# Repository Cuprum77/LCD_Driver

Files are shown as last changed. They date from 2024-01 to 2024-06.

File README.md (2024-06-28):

# LCD Driver Project

This repository contains my attempt at creating a "universal" driver board that fits most of the new 40 pin LCDs from China. These new LCDs all utilize a 40 pin flat flex cable, and utilize the ST7701 driver IC. 
This means that they are rather simple RGB devices, not too unlike the old VGA standard. 
The main goal however, is to have a board that does not require any system drivers, and utilize the standard connectors that are available on most SBCs, such as the Raspberry Pi, as well as most laptops and desktops.

## Table of contents
- [Supported LCDs](#supported-lcds)
- [Project layout](#project-layout)
- [License](#license)

## Supported LCDs

This table lists the LCDs that I have bought and tested with the driver board.

| Format | Size  | Resolution | Driver IC | Touch | Link | Additional notes |
| --- | ----- | --- | --- | ----- | --- | --- |
| Bar | 3.99" | 400x960 | ST7701 | Yes | [AliExpress](https://www.aliexpress.com/item/1005005622337201.html) | |
| Square | 3.95" | 480x480 | ST7701 | Yes | [AliExpress](https://www.aliexpress.com/item/1005005230886441.html) | NOT FULLY TESTED YET |

Alternatively, any other board that uses the ST7701 driver IC and with the following [pinout](./resources/PINOUT.md) should work with the driver board. However, you must generate a new ROM file for the FPGA.

## Project layout
- [UVVM_Light](https://github.com/UVVM/UVVM_Light) - The UVVM framework
- [bitfiles](bitfiles/) - FPGA bitfiles
- [edid](edid/) - EDID files for the LCDs
- [hardware](hardware/) - The KiCad project files for the driver boards
- [resources](resources/) - Resources for the project, such as datasheets
- [rom](rom/) - The ROM files for the FPGA projects
- [sim](sim/) - The UVVM testbenches for the driver boards
- [software](software/) - The software for the driver boards
- [vivado-library](https://github.com/Digilent/vivado-library/) - The Vivado library files for the driver boards

## License
This project is licensed under CERN Open Hardware License Version 2 - Strong Reciprocity (CERN-OHL-S-2.0). See [LICENSE](LICENSE) for more details.
Note that some files in this repository may be licensed under different licenses. Please check the respective files for more information.

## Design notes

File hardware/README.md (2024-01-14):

# Hardware

This repo contains the KiCAD files for the current hardware prototypes of the LCD driver board.

## Current version

The latest board manufactured is the [Breakout_1](Breakout_1/) board. This PCB is a breakout board for the LCD display, which allows for easy testing and verification of the display. It also contains a 40 pin header for the LCD display itself and a PMOD interface for hooking up with a FPGA board.

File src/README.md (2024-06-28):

# FPGA Source Files

This directory contains the FPGA source files for each specific FPGA board.
Each variant has its own subdirectory and the files may differ between the variants.

## ISE specifics

The ISE source files are located in the `ise` subdirectory, these contain the following file from [tmatsuya](https://github.com/tmatsuya)'s [repository](https://github.com/tmatsuya/i2c_edid): `i2c_edid.v`. Their respective license must be followed.

The folder `ise` also requires the user to request the `xapp460.zip` file from Xilinx, as it contains the DVI decoder used in this project. This is not possible to include in this repository as source code due to licensing restrictions.
It can be requested from their [application note](https://docs.amd.com/v/u/en-US/xapp460) near the end of the document.

The following files are required from the `XAPP460` note:
- `chnlbond.v`
- `dcminit.v`
- `decode.v`
- `DRAM16XN.v`
- `dvi_decoder.v`
- `phsaligner.v`
- `tmds_1c_1to10.v`

You also need to generate the appropriate edid.hex file for your display. This can be done with the python script [`edid_to_ise.py`](../edid/edid_to_ise.py) in the `edid` folder.

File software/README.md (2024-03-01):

# Firmware

The firmware, written in C/C++, is designed to operate on the RP2040 microcontroller. Its primary function is to read data from the capacitive touch sensor and transmit it to the host computer over USB.

The challenge lies in dealing with the capacitive touch sensor, an unidentified device. Fortunately, the touch controller on the display's flat flex cable retains its markings, making identification possible. The touch controller in use is the GT911 from Goodix, utilizing the I2C protocol.

Based on the similar AVR project by [azukovskij89](https://github.com/azukovskij89/AVR-MultiTouch).

## Chip Identification
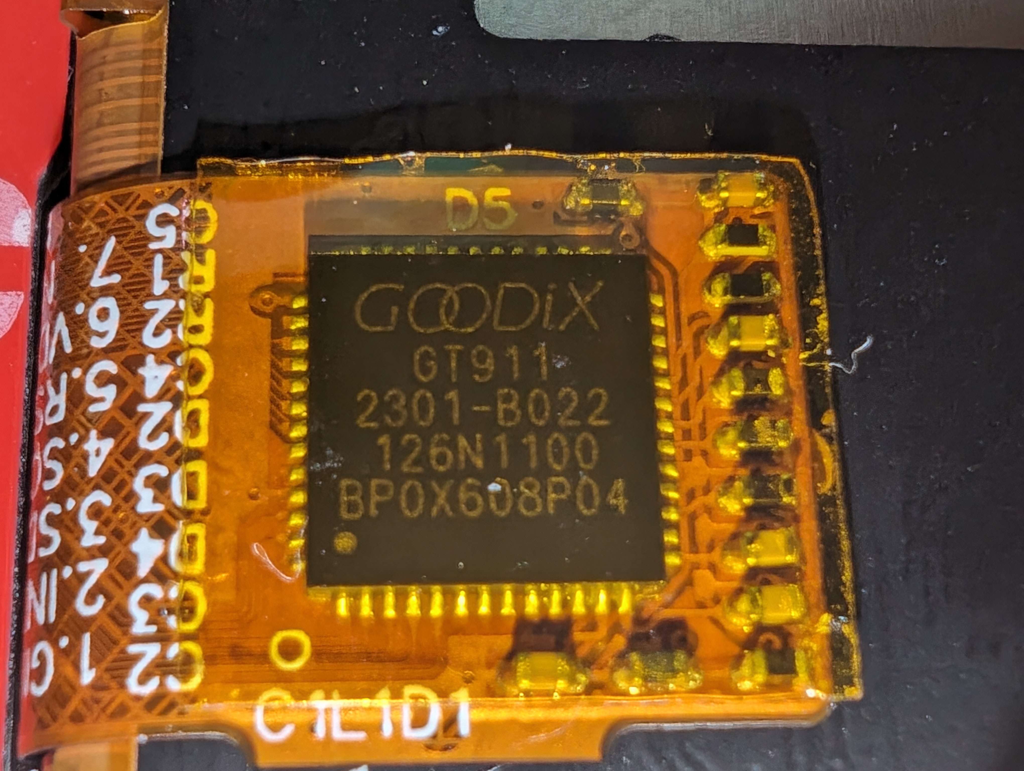
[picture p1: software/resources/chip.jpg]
Chip

Above is a close-up image of the GT911 chip on the flat flex cable of this specific display.

## Resources
- [Datasheet](../resources/GT911_v.09.pdf): Provides a brief overview of the chip's features and specifications.
- [Programming Guide](../resources/GT911%20Programming%20Guide_v0.1.pdf): Contains the register map and programming instructions.

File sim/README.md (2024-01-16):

# Simulation

This folder contains the files that were used for simulation of this project. Each folder contains a readme file that describes the simulation and its goals in more detail.

## Structure

The subfolders each contains a simulation for a specific part of the project, with the exception of the `UVVM` folder which contains the compiled UVVM library, which you need to compile in order to run the simulations.

The subfolders are structured as follows:
- [resetter](resetter/) - Simulation of the resetter
- [rgb](rgb/) - Simulation of the RGB controller for interfacing with the screen
- [spi](spi/) - Simulation of the SPI interface
- [sequencer](sequencer/) - Simulation of the sequencer (with the SPI interface)
- [top](top/) - Simulation of the top level module (with the sequencer and the RGB controller)

## Compiling UVVM

To compile UVVM for ModelSim, you need to open ModelSim and run the following snippet in the transcript window:

```tcl
do ../../UVVM_Light/script/compile.do ../../UVVM_Light ../UVVM
```

This should compile the UVVM library and place it in the `UVVM` folder.

## Running the simulations

Note, all UVVM based testbenches need to be configured to use VHDL-2008 or the simulation will throw errors!

Simply open up any of the project files in ModelSim and run the simulation.
The UVVM framework should be automatically loaded from the `UVVM` folder assuming you have compiled it correctly.

## UVVM Documentation

The documentation can be found [here](https://uvvm.github.io/), with the specific library used in this project located [here](https://uvvm.github.io/utility_library.html).

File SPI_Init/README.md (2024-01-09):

# FPGA SPI Hardware

This repo contains the hardware implementation of the SPI protocol for the FPGA. The SPI protocol is used to communicate with the LCD display.

## Table of contents
  - [SPI](#spi)
    - [Port map](#port-map)
    - [Bit Width](#bit-width)
  - [Sequencer](#sequencer)
    - [Port map](#port-map-1)
    - [Instruction Set](#instruction-set)
        - [cmd](#cmd)
        - [cmd_data](#cmd_data)
        - [size](#size)
        - [data](#data)
        - [data_cont](#data_cont)
        - [wait](#wait)
        - [Example](#example)
    - [ROM](#rom)
    - [ROM Generator](#rom-generator)
    - [Error](#error)

## SPI
The SPI is a state machine that makes sure the bits are sent out in the correct order and at the correct time. The implemented can be found in the file [spi.vhd](/spi.vhd).

Unlike other SPI implementations, this is master only. Meaning that it can only transmit data and not receive it. This is because the LCD display doesn't need to send any data back to the FPGA.

### Port map
| Port name | Direction | Size (bits) | Behavior | Description |
|---|---|---|---|---|
| clk | in | 1 | Active HIGH | Global clock |
| reset | in | 1 | Active HIGH | Global reset |
| spi_sda | out | 1 | | SPI data |
| spi_scl | out | 1 | | SPI clock |
| spi_cs | out | 1 | | SPI chip select |
| spi_dc | out | 1 | | SPI data command |
| send | in | 1 | Active HIGH | Start the transmission |
| set_dc | in | 1 | Active HIGH | Enables/Disables the SPI data command |
| done | out | 1 | LOW during transmission | Idle signal |
| data | in | 32 | MSB | Data to be sent over the bus |
| bit_width | in | 3 | | Number of bits to send over the bus |

### Bit Width
The `bit_width` variable is special, as it allows us to vary the number of bits being sent out over the SPI bus. This is very useful for some displays where the entire pixel should be sent at once, like the ST7789V displays. Thus it needs to be set to the correct setting for the number of bytes being sent:

| `bit_width` | Number of bits |
|---|---|
| 0 | 8 bits |
| 1 | 16 bits |
| 2 | 18 bits |
| 3 | 24 bits |
| 4 | 32 bits |

The state machine will start at the `bit_width` setting, so if you select 8 bits, it will start at index 7 of your data and work its way down to 0.

Warning; you still need to provide the entire 32 bits to the component even if you don't need every bit. Simply pad out the remaining bits with whatever you want if you use less than 32 bits.

## Sequencer
The sequencer is a state machine that takes in instructions from a generated ROM file and sends them to the SPI component. The implemented can be found in the file [sequencer.vhd](/sequencer.vhd).

This will execute every instruction in the ROM file, and will stop if it encounters an error. This is to prevent the sequencer from sending out garbage data to the LCD display.

When the sequencer is done, it will enter an idle state and stay there until it is reset.

### Port map

| Port name | Direction | Size (bits) | Behavior | Description |
|---|---|---|---|---|
| clk | in | 1 | Active HIGH | Global clock |
| reset | in | 1 | Active HIGH | Global reset |
| spi_sda | out | 1 | | SPI data |
| spi_scl | out | 1 | | SPI clock |
| spi_cs | out | 1 | | SPI chip select |
| spi_dc | out | 1 | | SPI data command |
| done | out | 1 | HIGH when done | Turns on when the module is done |
| sequence_error | out  | 1 | HIGH on error | Error signal |

### Instruction Set
The sequencer is used to send commands to the LCD display. To make it as versitile as possible, it uses a very simple instruction set.

An important thing to note is that the ROM is 32 bits wide, and loads two such words per cycle. This means that the first word is the instruction, and the second word is the payload.

| Instruction | Hex Code | Description |
|---|---|---|
| cmd | 0x10 | Send a command to the LCD display |
| size | 0x20 | Set the size of the data |
| data | 0x21 | Send data to the LCD display |
| wait | 0x30 | Delay in milliseconds |

#### cmd
The `cmd` instruction is used to send a command to the LCD display.
This behaves similarly to the `data` instruction, but it will also set the size to 8 bits automatically. Saves you a few instructions.

#### size
The `size` instruction is used to set the number of bits to send over the SPI bus. This is useful for commands that require a different number of bits to be sent.

The number written here should match one the possible values for the `bit_width` variable as described in [Bit Width](#bit-width).
Failure to match the `bit_width` variable will result in the module throwing an error.

#### data
The `data` instruction is used to send data to the LCD display.

Should always be preceded by a `size` instruction. If not, it will default to whatever was set before. Usually 8 bits if previous instruction was a `cmd` instruction.

#### wait
The `wait` instruction is used to delay the sequencer for a given number of milliseconds.

The sequencer will convert the number of milliseconds to the number of clock cycles required to wait.

The maximum wait time is 1 000 ms.

#### Example
The following example shows how to configure the cursor's x position on a ST7789V display;
```
cmd 0x2a
size 32
data 0x00 0x00 0xef 0x00
```
This psuedo code can be fed into the ROM generator to create a ROM.vhd file, found at [ROM Generator](#rom-generator).

### ROM
The ROM is a generated file that contains the instructions for the sequencer. It is a VHDL file that contains a constant array thats 32 bits wide and as long as the number of instructions in the ROM minus the number of comments.

This should be generated using the [ROM Generator](#rom-generator).

### ROM Generator
The ROM generator is a python script that takes in a text file containing the instructions for the Sequencer and outputs a VHDL file containing the ROM needed for the Sequencer to synthesize.

The script can be found at [rom_generator.py](/rom_generator.py).

The script expects a text file containing the instructions for the sequencer. Each instruction should be on its own line, and the instruction and its payload should be separated by a space.

An example of a valid instruction file for an ST7789V display can be found [here](/Example/st7789v_instructions.txt).

### Error
If the sequence encounters an unexpected instruction, it will throw an error and stop the sequence. This is to prevent the sequencer from sending out garbage data to the LCD display.

To exit the error state, the system needs to be reset.

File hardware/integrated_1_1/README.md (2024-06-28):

# Integrated Solution Rev 1.1

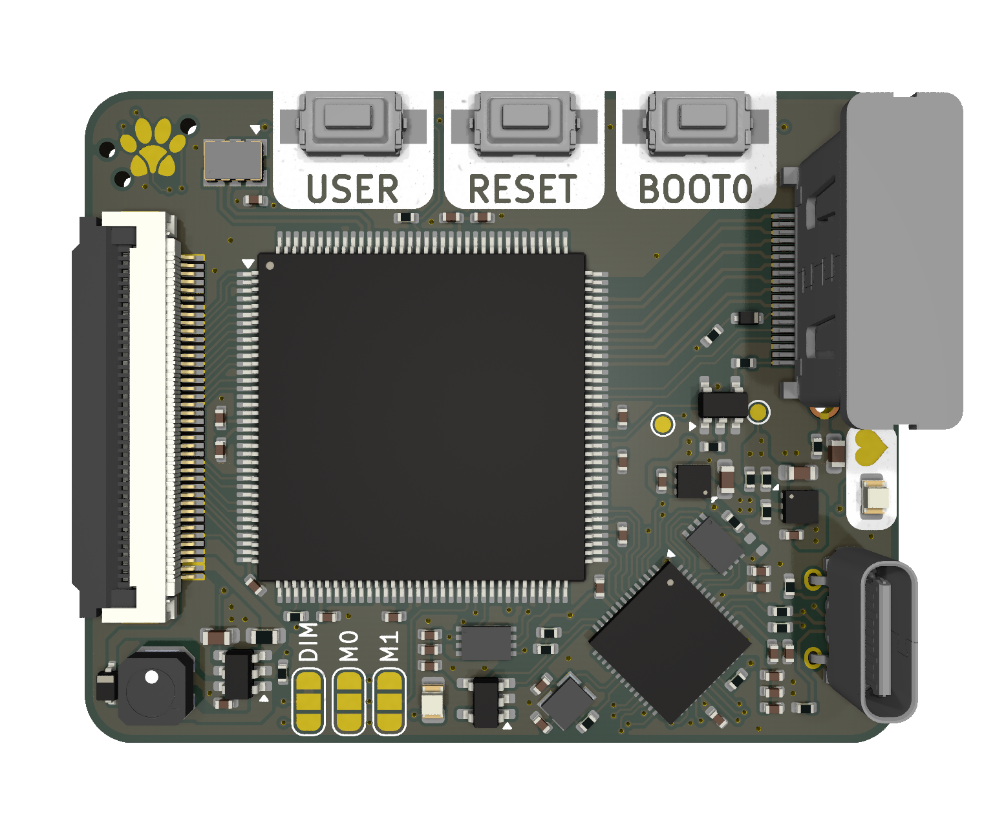
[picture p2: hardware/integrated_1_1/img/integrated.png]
Integrated


## Introduction

Even smaller than the previous revision, this design is a complete redesign of the previous, and implements fixes for the critical errors in the previous design. This design is still in the prototype phase and is not ready for production.

This is a PCB that integrates everything needed to drive the display. It is designed to sit on the back of the display without interfering with the display frame. It is specifically designed for the pinout of the newer non-standard displays that have come out of China in the recent years. Specifically those that support the RGB666 interface.

This design utilizes a Spartan 6 FPGA to drive the display. This was chosen over dedicated ASICs due to cost and adaptability. This should allow me to add features such as a splash screen or other custom features that are not possible with a dedicated ASIC.

## Features
- Spartan 6 FPGA [^1]
- DVI Input [^2]
- RP2040 microcontroller
- USB-C [^3] [^4]
- Backlight driver with dimming control
- LCD connector

[^1]: XC6SLX9-TQG144
[^2]: The DVI input is over a HDMI-like connector. This is due to licensing issues with the HDMI standard that I cannot afford to pay for. Any reference to HDMI in this project is purely for the sake of simplicity and is not meant to imply that this project is HDMI compatible.
[^3]: Does not support PD.
[^4]: Limited to USB 1.1 speeds. This is limited by the RP2040 which handles the USB interface.

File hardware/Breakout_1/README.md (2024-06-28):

# Breakout Board
Note, this is not a complete project. It lacks the necessary files to properly modify the design. This is purely out of the fact that this is a prototype and I am too lazy to properly document it.

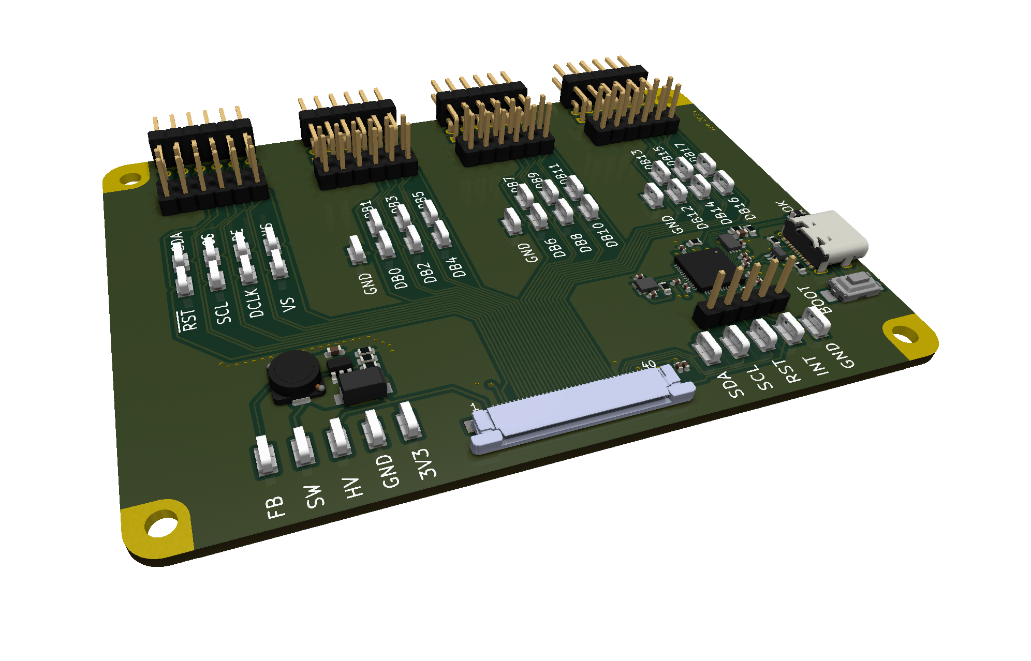
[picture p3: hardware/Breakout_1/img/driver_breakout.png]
Breakout design


This repo contains the KiCAD files for the first iteration of this project, the breakout board.

## Known Issues

These are the known issues with the current design:
- No pull-up resistors on the I2C lines
- No reset button
- No ability to power the board from the USB port (for the microcontroller)
- Difficult to add external power to the board
- More ground connections!
- Boost Converter is not capable of providing enough current for the display. Does not match the chips rated output.

## 3D Files

In the [3D](./3d/) folder you can find the 3D models for the board and a stand for the display to rest on.
The [stand](./3d/stand.stl) is a very crude design. It may not be very printable, but it works well enough for a prototype. 

This will not be developed further as there will not be a need for it in the final design.

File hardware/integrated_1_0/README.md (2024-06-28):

# Integrated Solution rev 1.0

## DO NOT REPRODUCE, CRITICAL ERRORS IN DESIGN

This design features a nasty error where the internal and IO power rails were accidentally swapped. Do not reproduce this design. A new revision is in the works.

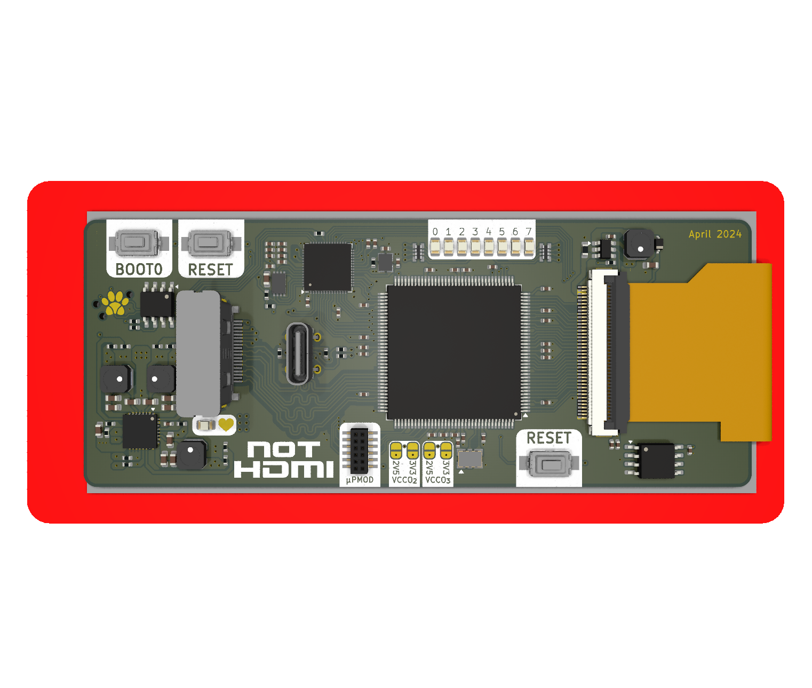
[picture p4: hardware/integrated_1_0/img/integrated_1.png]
Integrated


## Introduction

This is a PCB that integrates everything needed to drive the display. It is designed to sit on the back of the display without interfering with the display frame. It is specifically designed for the pinout of the newer non-standard displays that have come out of China in the recent years. Specifically those that support the RGB666 interface.

This design utilizes a Spartan 6 FPGA to drive the display. This was chosen over dedicated ASICs due to cost and adaptability. This should allow me to add features such as a splash screen or other custom features that are not possible with a dedicated ASIC.

## Features
- Spartan 6 FPGA [^1]
- DVI Input [^2]
- RP2040 microcontroller
- USB-C [^3] [^4]
- Backlight driver with dimming control
- LCD connector

## LCD Connector

The LCD connector itself is a ZIF 40 pin 0.5mm pitch connector.
The following pinout is in use, with some pins being possible to reconfigure in the FPGA:

TO BE ADDED

[^1]: XC6SLX9-TQG144
[^2]: The DVI input is over a HDMI-like connector. This is due to licensing issues with the HDMI standard that I cannot afford to pay for. Any reference to HDMI in this project is purely for the sake of simplicity and is not meant to imply that this project is HDMI compatible.
[^3]: Does not support PD.
[^4]: Limited to USB 1.1 speeds. This is limited by the RP2040 which handles the USB interface.

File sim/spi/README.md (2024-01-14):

# Simulation of the SPI

This is the files for the SPI simulation. The simulation is done using ModelSim and the [UVVM](https://github.com/UVVM/UVVM_Light) framework.

## Simulation

The goal of this simulation is to verify the functionality of the SPI interface and that it outputs the correct data when it should.

Note, the module is somewhat limited by design. It will not prevent the user from changing the input during transmission, and it will not ignore them either. This means that if the user changes the `data` input during transmission, the module will send the new data instead of the old. This is something to keep in mind when using the module, which is also why the `DONE` signal is important.

## Simulation Setup

There are a few things that I want to test with this module, and they are as follows:
- [Case 1](#case-1): Reset behaves as expected
- [Case 2](#case-2): `SEND` is ignored during reset and transmission
- [Case 3](#case-3): The `DONE` line is set correctly
- [Case 4](#case-4): Bit order can be changed

If these all pass, including a manual verification that the timings are correct, then the module should be ready for use.

### Case 1

The data lines should be set to their respective values after a reset:

| Line | Value |
| --- | ----- |
| SPI_SDA  | 0 |
| SPI_SCL  | 0 |
| SPI_CS | 1 |
| DONE | 1 |

Even if the `SEND` line is set to HIGH during reset, the module should not send any data.

### Case 2

The `SEND` line should be ignored during a reset state.
This means that if we want to transmit anything, but we reset it at the same time, it should still reset.

This is done by simply sending a reset and send pulse at the same time.

### Case 3

We need to verify that the `DONE` signal is kept HIGH when its not transmitting, and set LOW when it is.
This is critical for telling any higher level function that we are busy and shouldn't be bothered.

We will do this test with 8 bits, and the signal 0xAA.

### Case 4

Replicate [Case 3](#case-3), but do so with all the bit orders possible. Signal should be 0xAAAAAAAA to make it easy to spot visually.
We also care about the bits being sent in this scenario.

This test will conduct one transmission for each bit width setting.

## Results

The results can be viewed in the [log file](SPI_log.txt).
If there were any problems, they will show in the [alert file](_Alert.txt). This file will be empty if there were no problems.

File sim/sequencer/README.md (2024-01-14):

# Simulation of the Sequencer

This is the files for the Sequencer simulation. The simulation is done using ModelSim and the [UVVM](https://github.com/UVVM/UVVM_Light) framework.

## Simulation

The goal of this simulation is to verify the functionality of the sequencer and that it outputs the correct data when it should.
However, unlike the SPI simulation, this simulation will not provide any actual data to test. That is the job of the ROM.

This means you need to generate your own ROM file to test the sequencer with. This is done by ruinning the [ROM generator](../../SPI_Init/rom_generator.py) script.
The assembly file used for this simulation can be found [here](data.txt).

We will also not test any of the SPI functionality, as that module is assumed to be working correctly following a successful simulation.

## Simulation Setup

The sequencer is a lot simpler than the SPI module in terms of if it works or not. Either it outputs the SPI data correctly, or it doesn't.
This makes it significantly easier to test, as we can simply verify that the data is correct with a given input, such as the one provided in this folder.

Please note that the simulation will fail without the correct ROM file, as it is expecting the same data as the ROM file provides.

Note, there are only 8 bit instructions being used in this simulation.

## Results

The results can be viewed in the [log file](Sequencer_log.txt).
If there were any problems, they will show in the [alert file](_Alert.txt). This file will be empty if there were no problems.

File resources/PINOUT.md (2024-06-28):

# LCD Pinout

| Pin | Name | Description |
| --- | --- | --- |
| 1 | LEDA | Backlight Anode |
| 2 | LEDK | Backlight Cathode |
| 3 | LEDK | Backlight Cathode |
| 4 | GND | Ground |
| 5 | VCC | Power 3.3V |
| 6 | RST_n | Reset, active low |
| 7 | NC | Not connected |
| 8 | NC | Not connected |
| 9 | SDA | SPI Data |
| 10 | SCL | SPI Clock |
| 11 | CS | SPI Chip Select |
| 12 | DCLK | RGB Dot Clock |
| 13 | DE | RGB Data Enable |
| 14 | VSYNC | RGB Vertical Sync |
| 15 | HSYNC | RGB Horizontal Sync |
| 16 | DB0 | RGB Data Bit 0 (Blue) |
| 17 | DB1 | RGB Data Bit 1 (Blue) |
| 18 | DB2 | RGB Data Bit 2 (Blue) |
| 19 | DB3 | RGB Data Bit 3 (Blue) |
| 20 | DB4 | RGB Data Bit 4 (Blue) |
| 21 | DB5 | RGB Data Bit 5 (Blue) |
| 22 | DB6 | RGB Data Bit 6 (Green) |
| 23 | DB7 | RGB Data Bit 7 (Green) |
| 24 | DB8 | RGB Data Bit 8 (Green) |
| 25 | DB9 | RGB Data Bit 9 (Green) |
| 26 | DB10 | RGB Data Bit 10 (Green) |
| 27 | DB11 | RGB Data Bit 11 (Green) |
| 28 | DB12 | RGB Data Bit 12 (Red) |
| 29 | DB13 | RGB Data Bit 13 (Red) |
| 30 | DB14 | RGB Data Bit 14 (Red) |
| 31 | DB15 | RGB Data Bit 15 (Red) |
| 32 | DB16 | RGB Data Bit 16 (Red) |
| 33 | DB17 | RGB Data Bit 17 (Red) |
| 34 | GND | Ground |
| 35 | TP_INT / NC | Touch Panel Interrupt or Not connected |
| 36 | TP_SDA / NC | Touch Panel SDA or Not connected |
| 37 | TP_SCL / NC | Touch Panel SCL or Not connected |
| 38 | TP_RST / NC | Touch Panel Reset or Not connected |
| 39 | TP_VCC / NC | Touch Panel Power or Not connected |
| 40 | GND | Ground |

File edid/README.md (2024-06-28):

# EDID Data

This folder contains the EDID data for the display used in this project. Already generated binaries are included for tested displays in the [bin](bin/) folder.

## Table of contents
- [Replacing the EDID Data](#replacing-the-edid-data)
- [Timing Data](#timing-data)
- [Generating or Modifying EDID Data](#generating-or-modifying-edid-data)
- [Modeline to EDID](#modeline-to-edid)

## Replacing the EDID Data (Vivado Only)

To replace the EDID data, you need to identify all the files named "dgl_720p_cea.data" in the project. I am unsure if you only need to replace the one that Vivado copied into the project folder, or the one in the IP core as well. I simply replaced both.
These files are typically found in both the [fpga folder](../fpga/xilinx/xilinx.srcs/sources_1/ip/dvi2rgb_0/src/dgl_720p_cea.data) and the [IP core folder](../vivado-library/ip/dvi2rgb/src/dgl_720p_cea.data).

This however should be done manually, as the IP core is a submodule.

## Timing Data

The datasheets has a great minimum and maximum timing specification for the displays that I have tested, but sadly they are not suitable for real world use.
This is a limitation of most GPUs, as they are no longer made to work with small displays like these. This is where the [Free86 modeline generator](https://xtiming.sourceforge.net/cgi-bin/xtiming.pl) comes in. It can generate appropriate timings for the display given our resolution and refresh rate, making sure we are within the capabilities of a modern GPU! By padding the data with a larger blanking interval, it can be made to work with most GPUs that I have tested. (Which isn't that many to be honest)

## Generating or Modifying EDID Data

The binary file is generated using the [Deltacast EDID Editor](https://www.deltacast.tv/products/free-software/e-edid-editor). It is a "free" tool, but requires registration. This outputs a pure binary file, which in itself is not very useful. So I wrote a simple python script to convert it to the data file used by the Digilent IP powering the HDMI interface. 

There are two scripts in this folder for converting to a more readable format:
- [edid_to_data.py](edid_to_data.py) - Converts the binary EDID file to a data file.
- [modeline_to_edid.py](modeline_to_edid.py) - Converts a modeline to EDID data.

## Modeline to EDID

Using the 400x960 pixel display as an example, we can input its resolution into the Free86 modeline generator to get the following modeline:
```
Modeline "400x960@60" 36.48 400 432 568 600 960 979 989 1009
```

With some arithmetic we can convert this to the EDID data we need to fill into the EDID editor.

These values are not immediately obvious how they fit into the EDID format, luckily its rather easy to calculate these values!

### Automatically
If you're like me, you dont want to do this by hand.
This is why I included the following python script [modeline_to_edid.py](modeline_to_edid.py) which takes the entire modeline string from the Free86 website output as an argument.

Example usage:
```bash
python modeline_to_edid.py Modeline "400x960@60" 36.48 400 432 568 600 960 979 989 1009
```

### Manually
However, if you prefer to do this manually, here is how you can calculate the values:
```
Front Porch = Sync Start - Display
```

```
Back Porch = Total - Display
```

```
Sync Width = Sync End - Sync Start
```

```
Blanking = Front Porch + Sync Width + Back Porch
```

### Results
Both the manual and automatic approach should generate the following values, given the example input above:
```
Pixel Clock:      36.48 MHz

H. Active:       400
H. Blank:        200
H. Front Porch:   32
H. Sync Width:   136
H. Image Size:   600

V. Active:       960
V. Blank:         49
V. Front Porch:   19
V. Sync Width:    10
V. Image Size:  1009
```

You simply type these values into the corresponding input of the Detailed Timings / Display Descriptor section of the EDID editor and you're almost done!

Lastly, you need to make sure that the "Sync Signal Definition" is set to "Digital Seperate" and both the sync signals should be unchecked. This is to avoid any issues with the display not being able to sync up with the signal.

Your "Detailed Timings / Display Descriptor" section should now look like this:
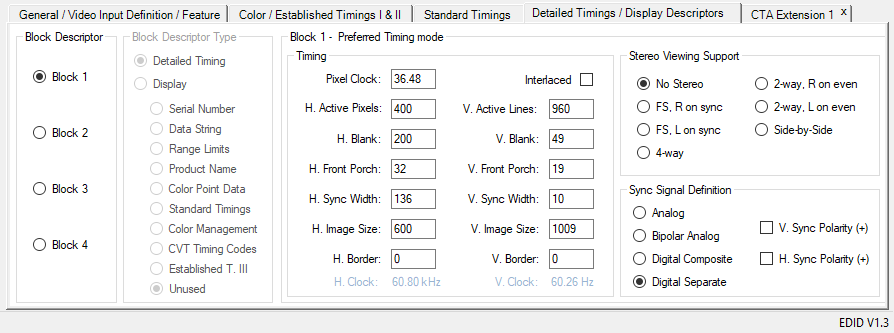
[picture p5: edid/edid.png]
EDID Screen


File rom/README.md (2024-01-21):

# ROM

The ROM is a generated file that contains the instructions for the sequencer. It is a VHDL file that contains a constant array thats 32 bits wide and as long as the number of instructions in the ROM minus the number of comments.

This should be generated using the [ROM Generator](#rom-generator).

## ROM Generator

The ROM generator is a terminal script that takes in the text file as an argument and outputs a VHDL file containing the ROM.
The script can be found at [rom_generator.py](rom/rom_generator.py).

The script expects a text file containing the instructions for the sequencer. Each instruction should be on its own line, and the instruction and its payload should be separated by a space.

An example of a valid instruction file for an ST7789V display can be found [here](rom/example/st7789v_instructions.txt).

## Usage

The script can be run using the following command:
```
python3 rom_generator.py -i <input_file>
```
Where `<input_file>` is the text file containing the instructions.

The script will output a VHDL file containing the ROM. This file can then be found in the same folder as the script.

## Example

Example initializer assembly files can be found in the [example](example/) folder.
The ST7701S display initializer was found [here](https://www.buydisplay.com/bar-type-3-99-inch-400x960-ips-tft-lcd-display-spi-rgb-interface). Note, as I bought mine from Aliexpress, I have no personal experience with this store. I am not affiliated with them in any way.

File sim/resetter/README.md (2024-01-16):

# Resetter simulation

This is the files for the Sequencer simulation. The simulation is done using ModelSim and the [UVVM](https://github.com/UVVM/UVVM_Light) framework.

## Simulation

This is a very simple testbench, and like the others, UVVM really wasn't necessary.
Despite that, I want to use it more, so I'm using it here.

The goal of this simulation is like every other simulation, to verify the functionality of the module.
This is done by setting a few goals our module should achieve, and then verifying that it does so.

## Simulation Goals

The goals of this simulation are as follows:
1. Reset should be high for 10 ms
2. Reset should be low for 100 ms
3. Reset should be high for 10 ms
4. A done signal should be sent when the reset is done

## Simulation Results

The results can be viewed in the [log file](Resetter_log.txt).

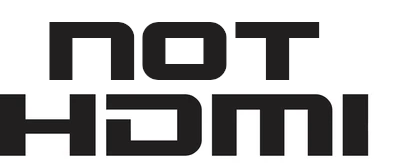
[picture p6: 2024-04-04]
hardware/integrated_1_0/resources/not_hdmi.png

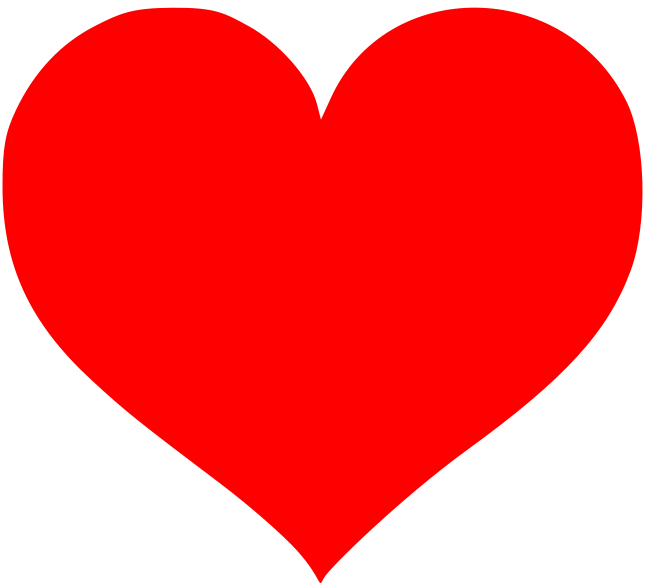
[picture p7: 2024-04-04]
hardware/integrated_1_0/resources/645px-Love_Heart_SVG.svg.png

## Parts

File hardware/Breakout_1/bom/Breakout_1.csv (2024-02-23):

Reference | Value | Datasheet | Footprint | Qty | DNP
C1,C3,C12,C22 | 1u | ~ | -- mixed values -- | 4
C2,C6,C9,C10,C13,C14,C15,C16,C17,C18,C19 | 100n | ~ | KiCAD Library:C_0402_1005Metric | 11
C4,C5 | 8p | ~ | Capacitor_SMD:C_0402_1005Metric | 2
C7,L1 | 10u | ~ | -- mixed values -- | 2
C8 | 2u2 | ~ | KiCAD Library:C_0603_1608Metric | 1
D1 | LED | ~ | Diode_SMD:D_0805_2012Metric | 1
D2 | SS14 | https://www.tme.eu/Document/39e1c2d2c354f63d74e9a2edb2156b4b/SS14-E3_61T.pdf | KiCAD Library:DIOM5227X270N | 1
DS1 | ST7701_IPS_3.99_TOUCH |  | KiCAD Library:AMPHENOL_F32Q-1A7H1-11040 | 1
J1,J2,J3,J4,J5,J6,J7,J8 | Conn_01x12 | ~ | -- mixed values -- | 8
J9 | USB4105-GF-A-120 | https://www.usb.org/sites/default/files/documents/usb_type-c.zip | Connector_USB:USB_C_Receptacle_GCT_USB4105-xx-A_16P_TopMnt_Horizontal | 1
J10 | Conn_01x05 | ~ | Connector_PinHeader_2.54mm:PinHeader_1x05_P2.54mm_Vertical | 1
R1,R2 | 5k1 | ~ | Cuprum:R_0603_1608Metric | 2
R3 | 270 | ~ | KiCAD Library:R_0603_1608Metric | 1
R4 | 10K | ~ | KiCAD Library:R_0603_1608Metric | 1
R5,SW1 | DNF | ~ | -- mixed values -- | 2
R6 | 1k | ~ | KiCAD Library:R_0603_1608Metric | 1
R7,R9 | 1M | ~ | Cuprum:R_0603_1608Metric | 2
R8 | 105k | ~ | Cuprum:R_0603_1608Metric | 1
TP1,TP4,TP5,TP6,TP7,TP8,TP9,TP10,TP11,TP12,TP13,TP14,TP15,TP16,TP17,TP18,TP19,TP20,TP21,TP22,TP23,TP24,TP25,TP26,TP27,TP28,TP29,TP30,TP31,TP32,TP33,TP34,TP35,TP36,TP37,TP38,TP39,TP40,TP41 | TestPoint | ~ | KiCAD Library:TestPoint_Keystone_5019_Minature_No_Silkscreen | 39
U1 | AP3015 |  | Package_TO_SOT_SMD:SOT-23-5 | 1
U2 | W25Q16JV | http://www.winbond.com/resource-files/w25q32jv%20revg%2003272018%20plus.pdf | KiCAD Library:W25Q16JVUXIQ TR | 1
U3 | USBUF02W6 |  | KiCAD Library:SOT65P210X110-6N | 1
U4 | RP2040 | https://datasheets.raspberrypi.com/rp2040/rp2040-datasheet.pdf | Package_DFN_QFN:QFN-56-1EP_7x7mm_P0.4mm_EP3.2x3.2mm | 1
Y1 | 12MHz | ~ | KiCAD Library:ECS120836CKMTR3 | 1

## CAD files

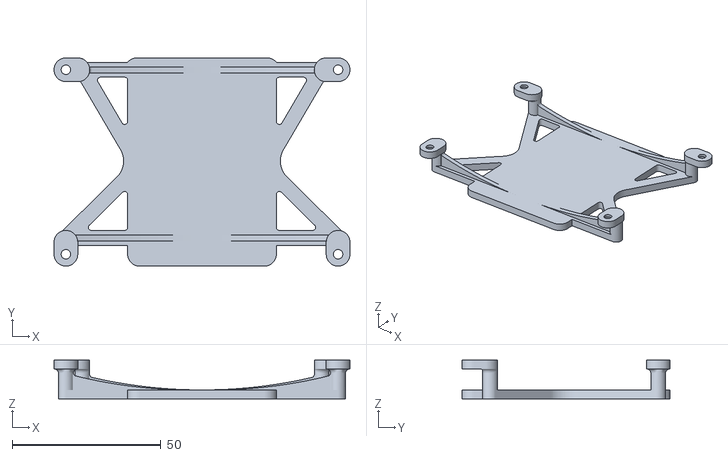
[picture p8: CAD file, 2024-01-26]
hardware/Breakout_1/3d/stand.stl
99.5 x 70.0 x 13.0

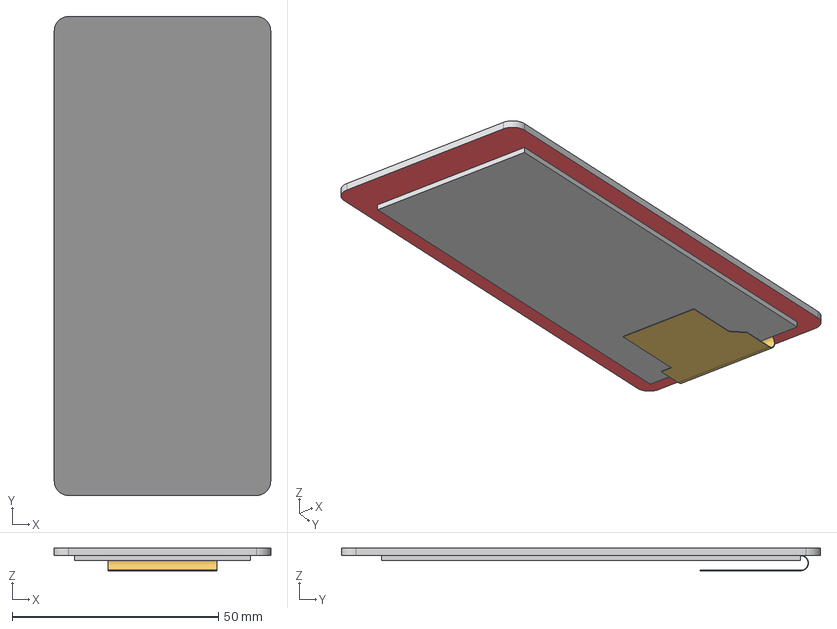
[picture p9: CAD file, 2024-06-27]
hardware/integrated_1_1/3d/LCD_3_99.step
52.5 x 116.1 x 5.47 mm

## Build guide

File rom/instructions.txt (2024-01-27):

; reset the display
cmd 0x1
; set the display to sleep out
cmd 0x11
; set the pixel format
cmd 0x3a
data 0x55
; set rotation
cmd 0x36
data 0x00
; set the display pointer's x position
cmd 0x2a
data 0 0 239 0 ; max width 240 px
; set the display pointer's y position
cmd 0x2b
data 0 0 319 0 ; max height 320 px
; turn on the display inversion
cmd 0x21
; normal mode on
cmd 0x13
; enable the display
cmd 0x29

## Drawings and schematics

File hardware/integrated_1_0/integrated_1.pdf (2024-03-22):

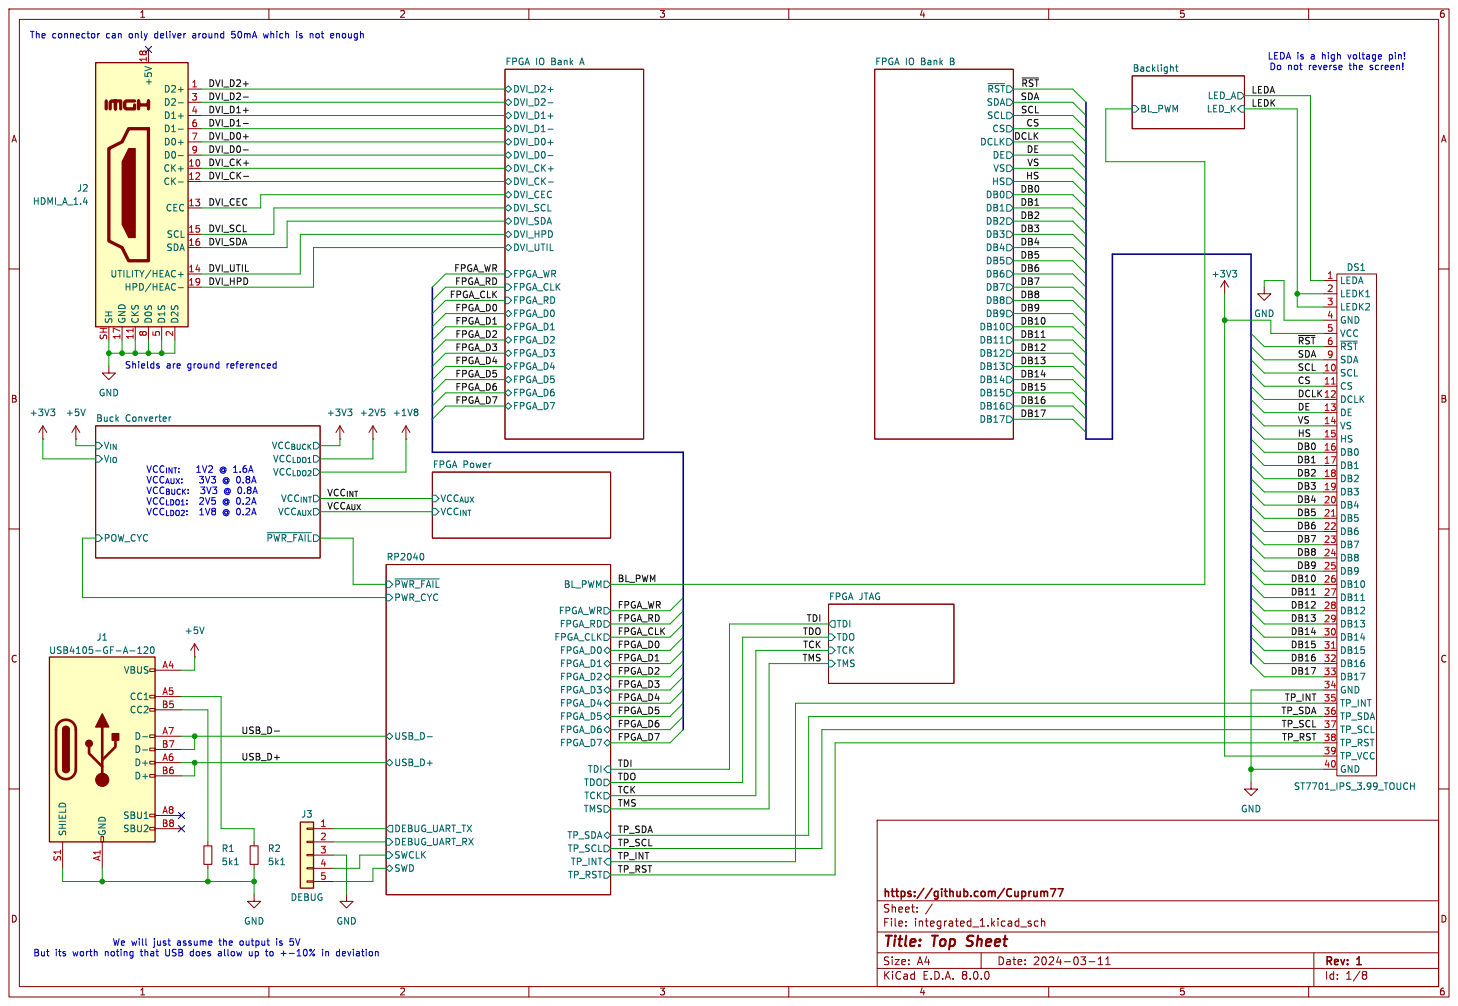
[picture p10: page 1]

SCL ~{RST} CS
SDA
SCL CS DCLKDE DB3 DB4 DB2 DB1 DB13 DB14 DB12 DB17 DB15 DB16 DB5 DB6 DB7 DB9 DB8 DB10 DB11HS DB0VS
LEDA 1 SCL 10 CS 11 DCLK 12 DE 13 VS 14 HS 15 DB0 16 DB1 17 DB2 18 DB3 19
LEDK1 2 DB4 20 DB5 21 DB6 22 DB7 23 DB8 24 DB9 25 DB10 26 DB11 27 DB12 28 DB13 29
LEDK2 3 DB14 30 DB15 31 DB16 32 DB17 33 GND 34 TP_INT 35 TP_SDA 36 TP_SCL 37 TP_RST 38 TP_VCC 39 GND 4 GND 40

Id: 1/8 Title: Top Sheet File: integrated_1.kicad_sch Sheet: / https://github.com/Cuprum77

We will just assume the output is 5V

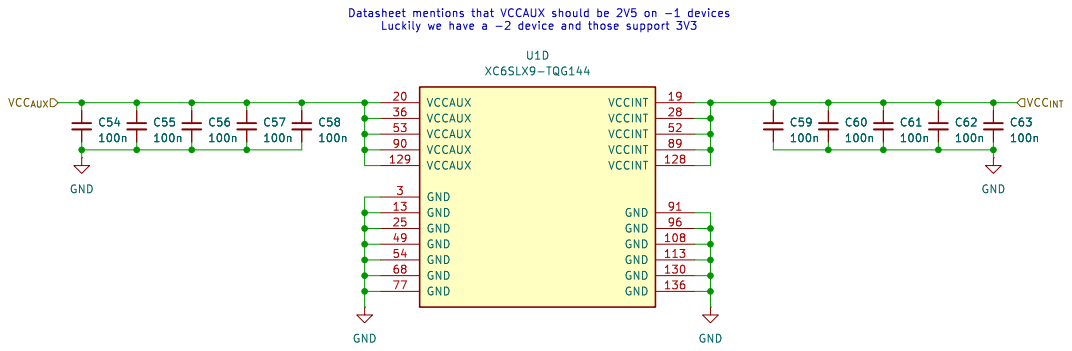
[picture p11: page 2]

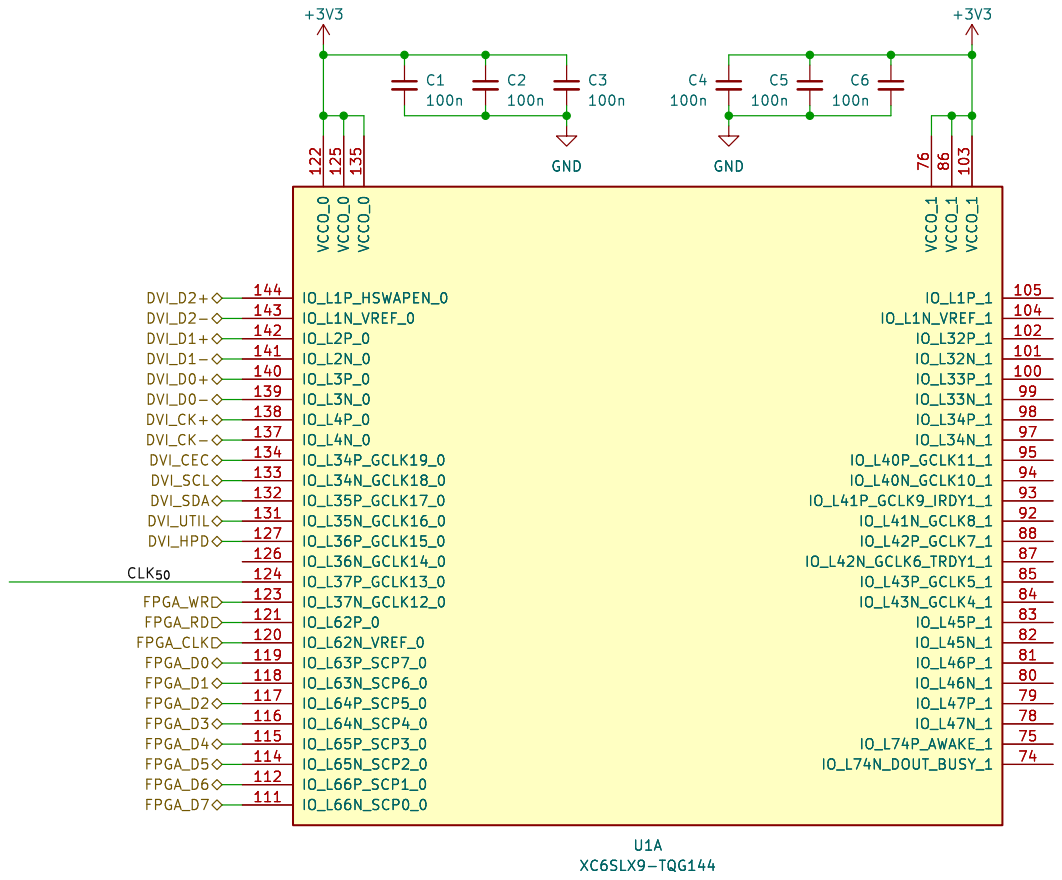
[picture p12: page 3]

Id: 3/8 Title: FPGA IO Bank A

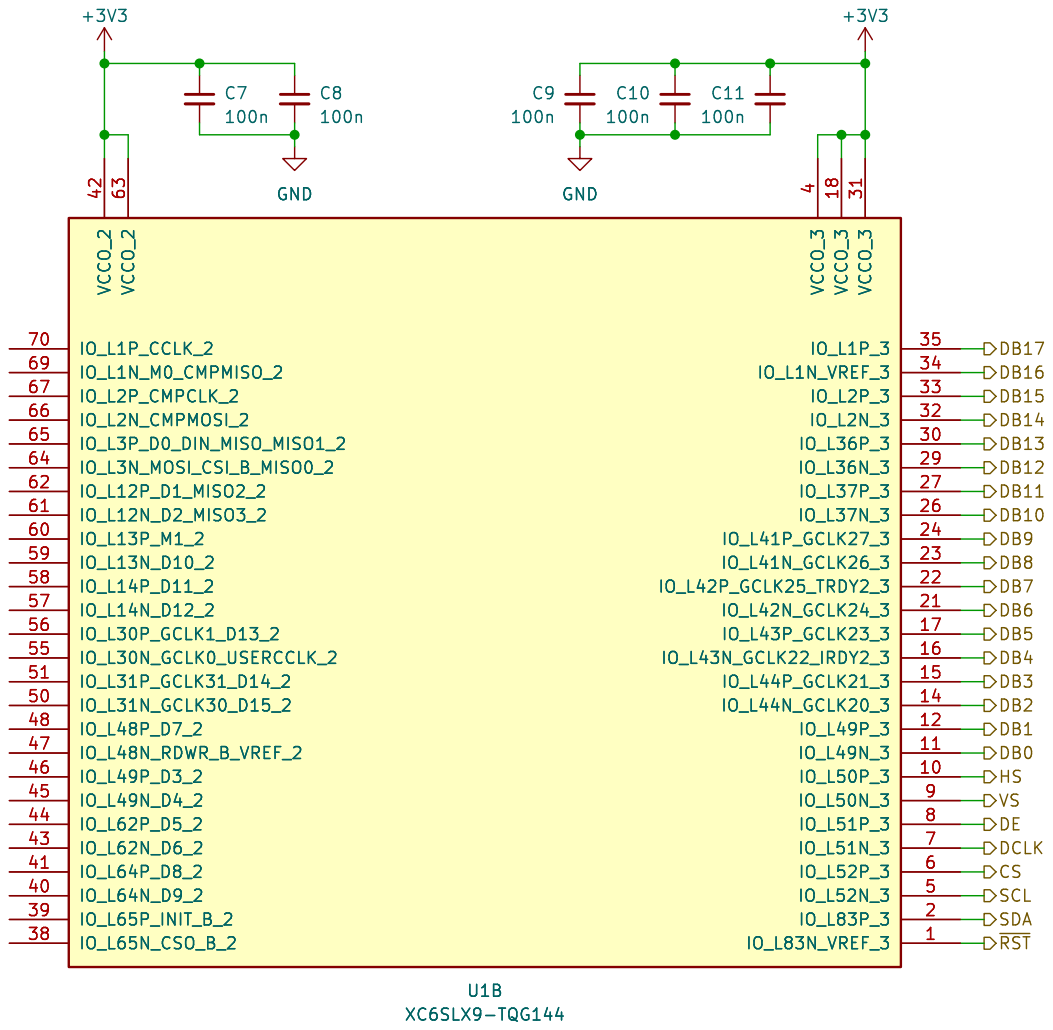
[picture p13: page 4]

Id: 4/8 Title: FPGA IO Bank B

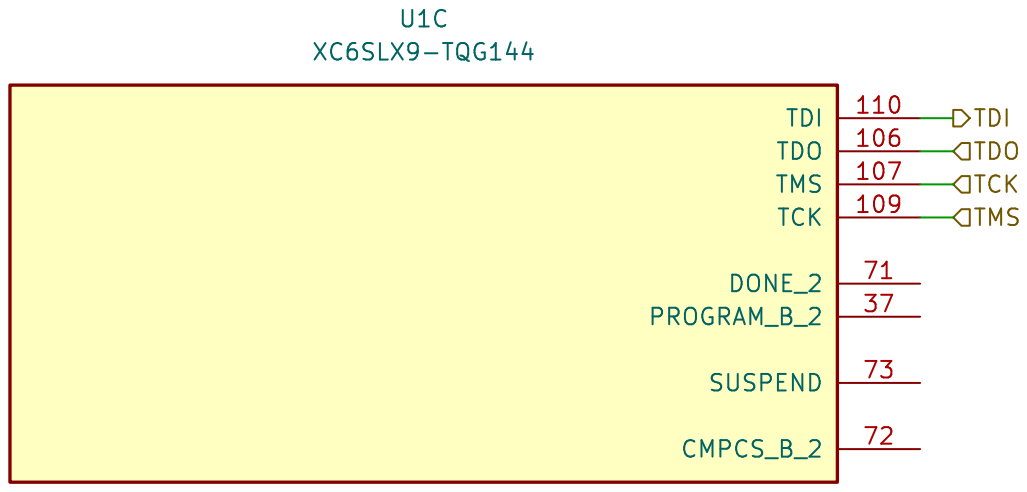
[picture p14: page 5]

File: fpga_jtag.kicad_sch Sheet: /FPGA JTAG/ https://github.com/Cuprum77

Id: 5/8 Title: FPGA JTAG Interface

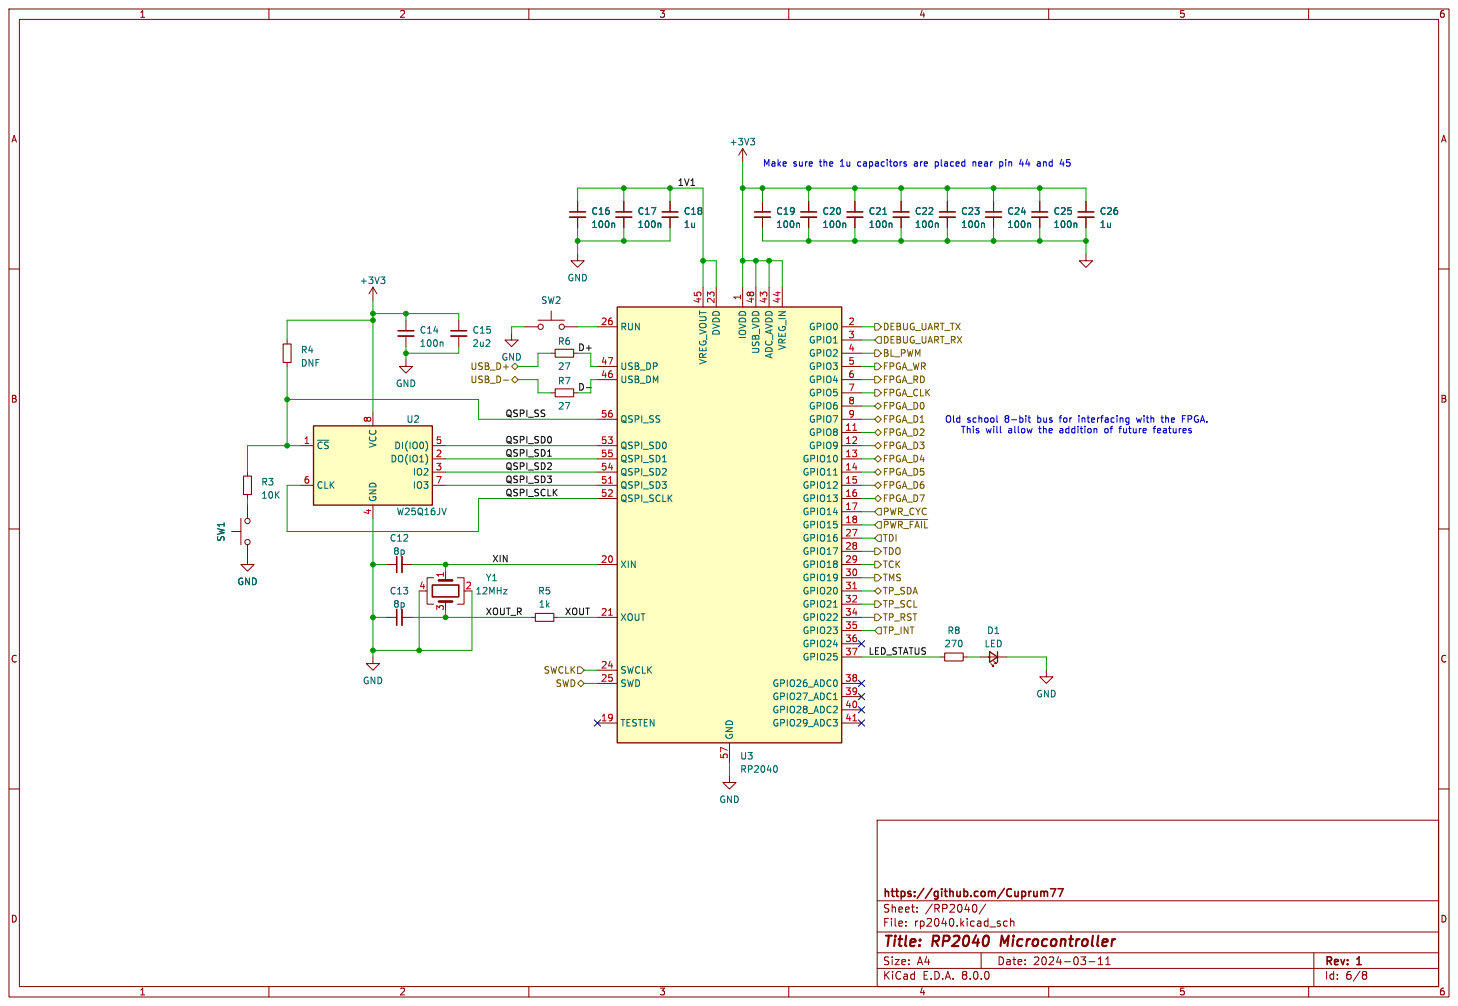
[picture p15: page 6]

1 GPIO8 11 GPIO9 12 GPIO10 13 GPIO11 14 GPIO12 15 GPIO13 16 GPIO14 17 GPIO15 18 TESTEN 19 GPIO0 2 XIN 20 XOUT 21 DVDD 23 SWCLK 24 SWD 25 RUN 26 GPIO16 27 GPIO17 28 GPIO18 29 GPIO1 3 GPIO19 30 GPIO20 31 GPIO21 32 GPIO22 34 GPIO23 35 GPIO24 36 GPIO25 37 GPIO26_ADC0 38 GPIO27_ADC1 39 GPIO2 4 GPIO28_ADC2 40 GPIO29_ADC3 41 ADC_AVDD 43 VREG_IN 44 VREG_VOUT 45 USB_DM 46 USB_DP 47 USB_VDD 48 GPIO3 5 QSPI_SD3 51 QSPI_SCLK 52 QSPI_SD0 53 QSPI_SD2 54 QSPI_SD1 55 QSPI_SS 56 GND 57 GPIO4 6 GPIO5 7 GPIO6 8 GPIO7 9 U3 RP2040

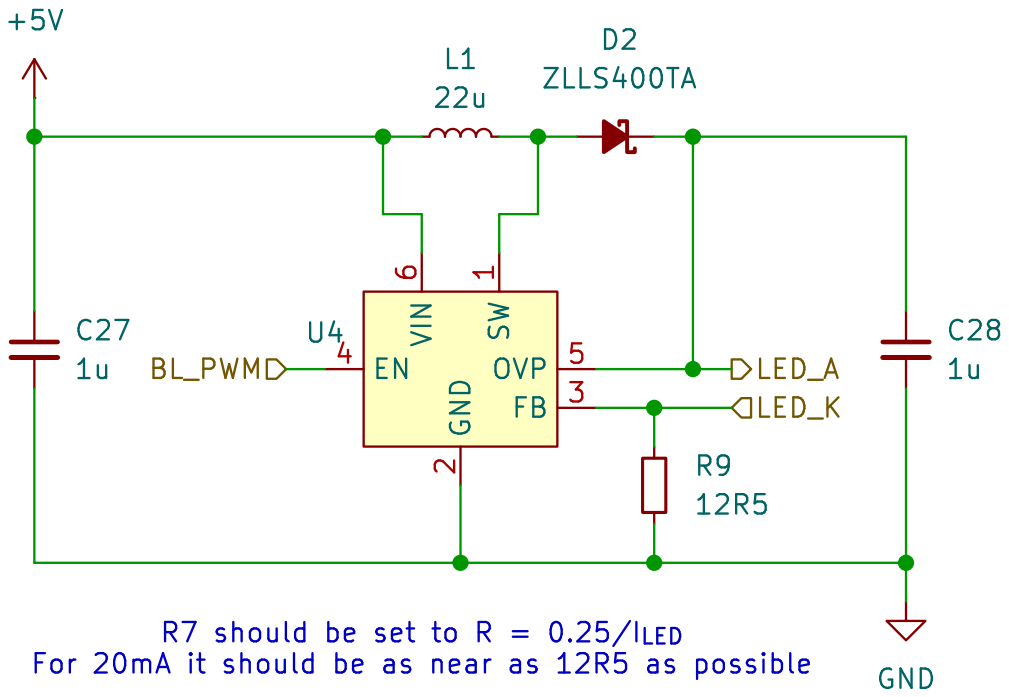
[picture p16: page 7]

2 FB 3 EN 4 OVP 5 VIN

LED_K R7 should be set to R = 0.25/I_{LED} For 20mA it should be as near as 12R5 as possible

Id: 7/8 Title: Backlight Driver File: backlight.kicad_sch Sheet: /Backlight/

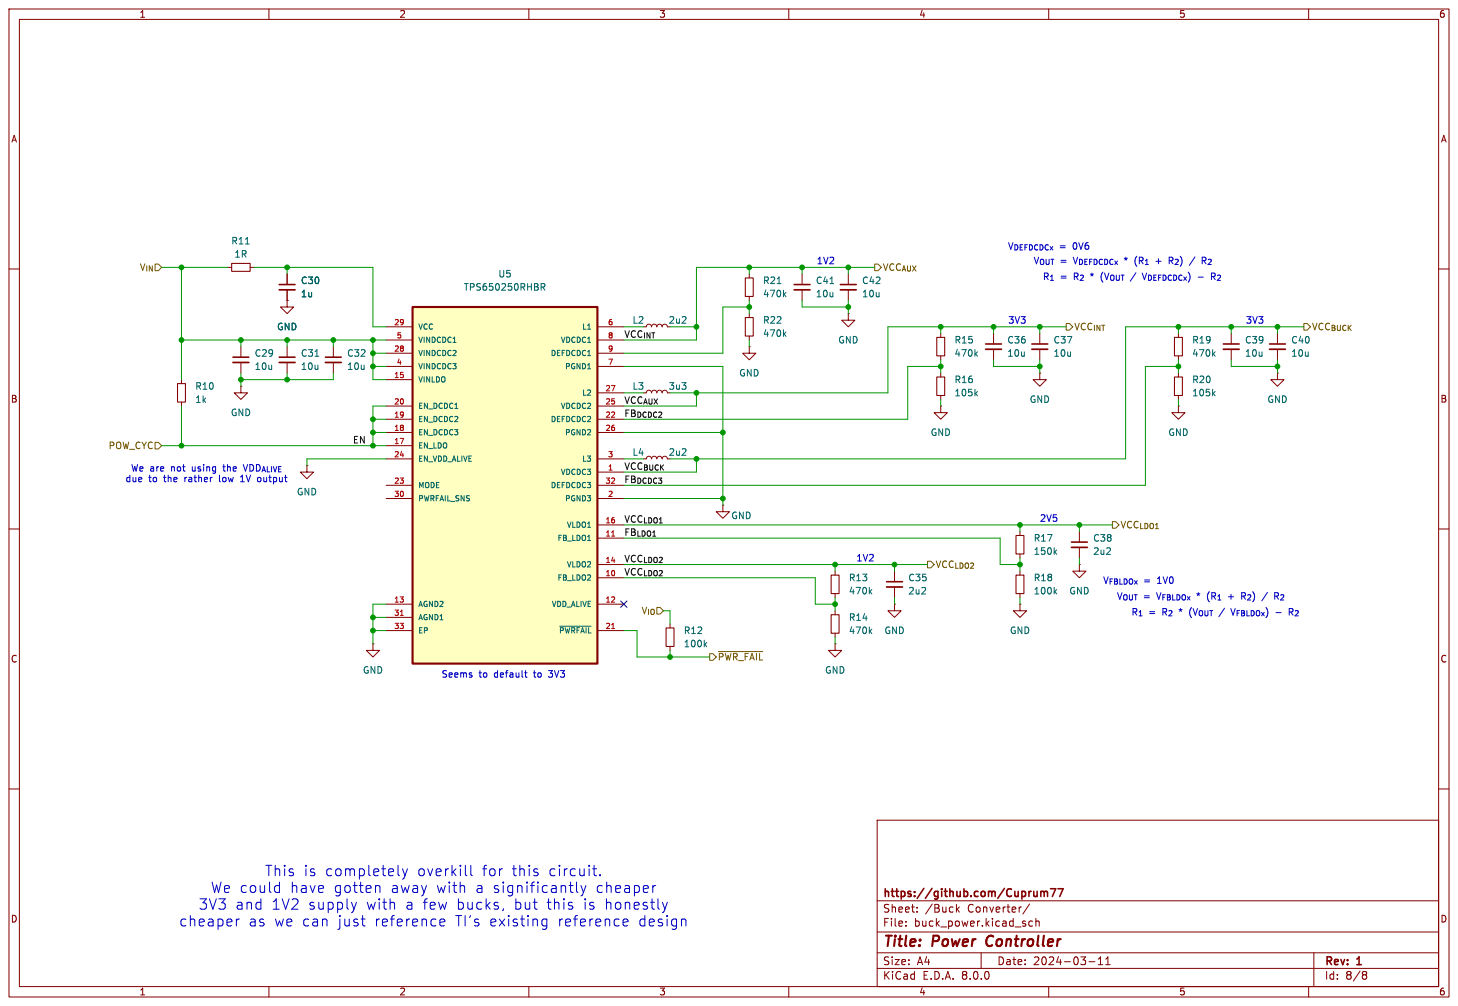
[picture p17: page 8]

3V3 and 1V2 supply with a few bucks, but this is honestly
cheaper as we can just reference TI's existing reference design

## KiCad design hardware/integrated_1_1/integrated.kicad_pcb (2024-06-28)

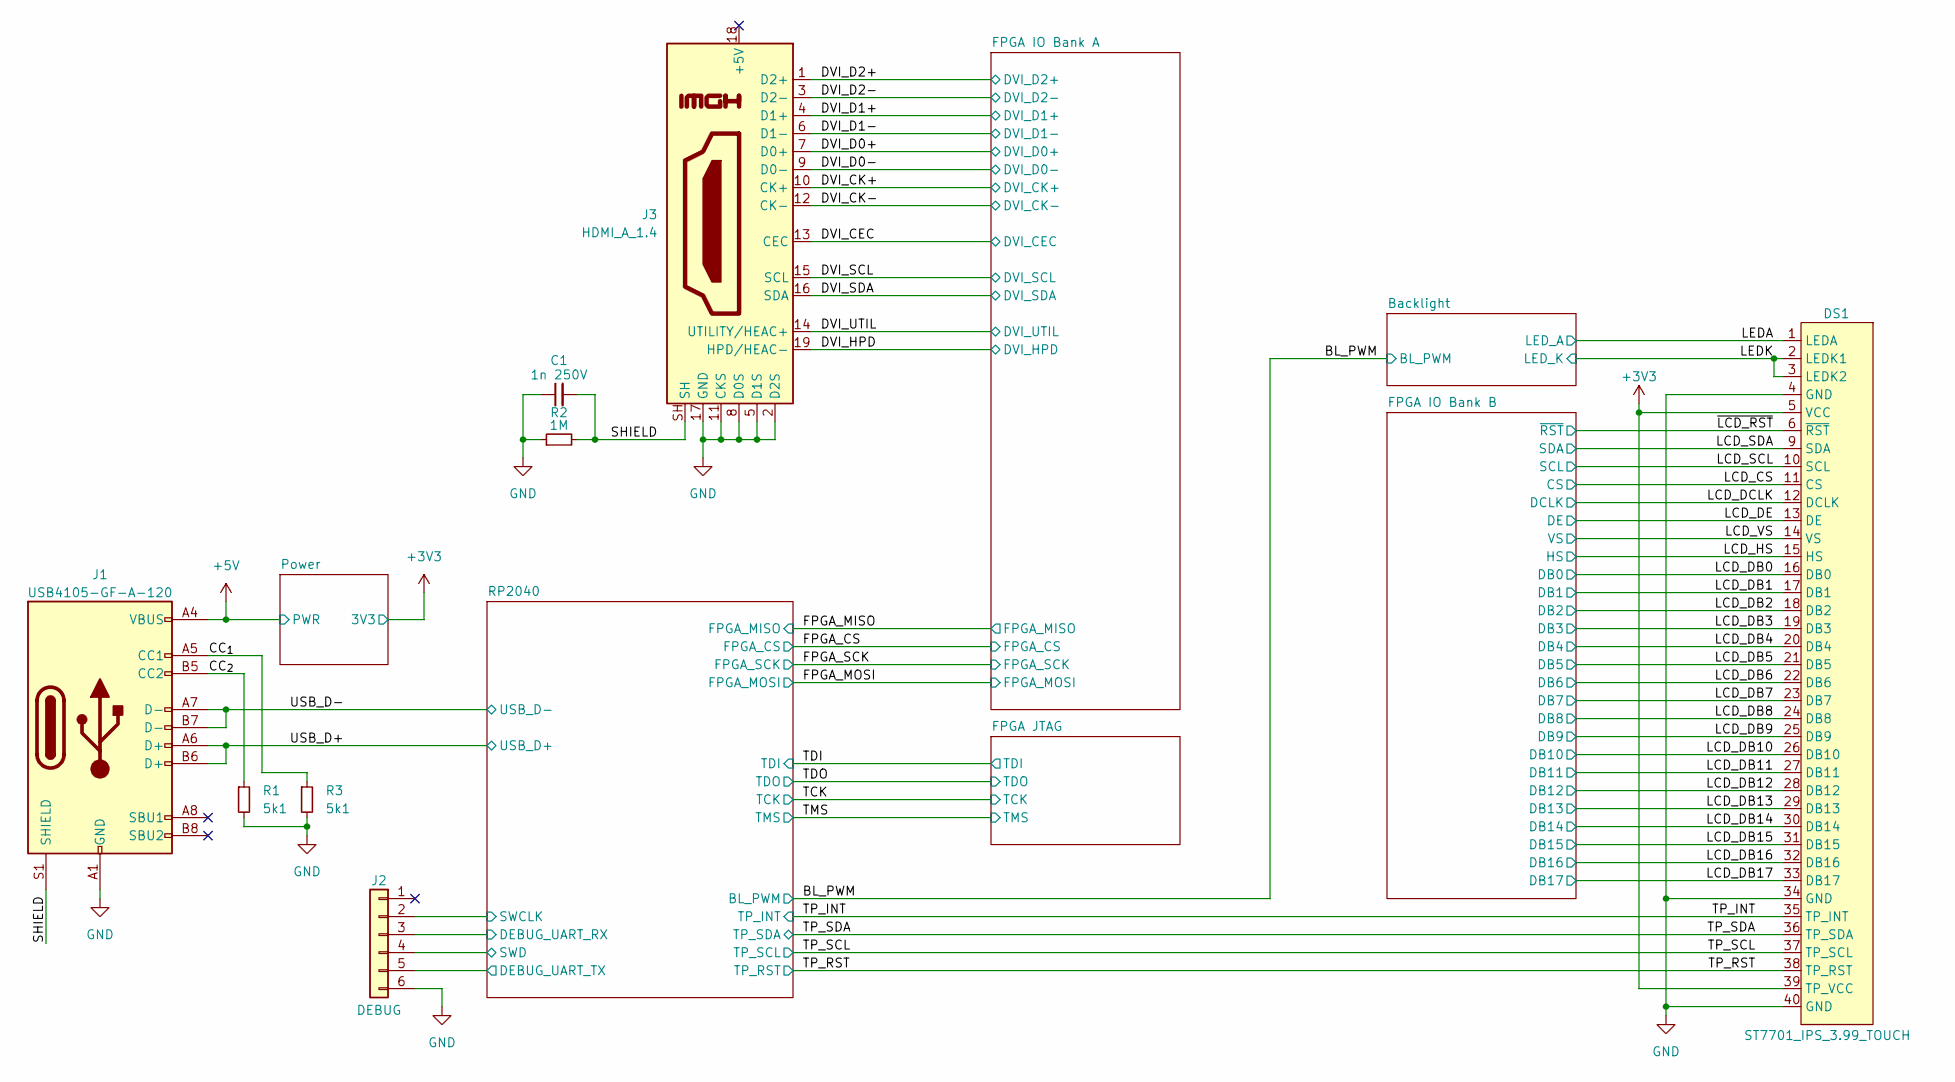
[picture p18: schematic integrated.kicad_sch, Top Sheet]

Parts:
C1: 1n 250V; C_0603_1608Metric
DS1: ST7701_IPS_3.99_TOUCH; GCT_FFC2B35-40-G_REVA2_INV
J1: USB4105-GF-A-120; CONN_217182-0001_MOL
J2: DEBUG; Paw-Connect_RevB_TC2030-IDC-NL_2x03_P1.27mm_Vertical
J3: HDMI_A_1.4; MOLEX_476591102
R1, R3: 5k1; R_0402_1005Metric
R2: 1M; R_0402_1005Metric

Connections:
+3V3: DS1.5 (VCC), DS1.39 (TP_VCC); also elsewhere on the board
+5V: J1.A4 (VBUS), J1.A9 (VBUS), J1.B4 (VBUS), J1.B9 (VBUS); also elsewhere on the board
/CC_{1}: J1.A5 (CC1), R3.1
/CC_{2}: J1.B5 (CC2), R1.1
/DVI_CEC: J3.13 (CEC); also elsewhere on the board
/DVI_CK+: J3.10 (CK+); also elsewhere on the board
/DVI_CK-: J3.12 (CK-); also elsewhere on the board
/DVI_D0+: J3.7 (D0+); also elsewhere on the board
/DVI_D0-: J3.9 (D0-); also elsewhere on the board
/DVI_D1+: J3.4 (D1+); also elsewhere on the board
/DVI_D1-: J3.6 (D1-); also elsewhere on the board
/DVI_D2+: J3.1 (D2+); also elsewhere on the board
/DVI_D2-: J3.3 (D2-); also elsewhere on the board
/DVI_HPD: J3.19 (HPD/HEAC-); also elsewhere on the board
/DVI_SCL: J3.15 (SCL); also elsewhere on the board
/DVI_SDA: J3.16 (SDA); also elsewhere on the board
/LCD_CS: DS1.11 (CS); also elsewhere on the board
/LCD_DB0: DS1.16 (DB0); also elsewhere on the board
/LCD_DB1: DS1.17 (DB1); also elsewhere on the board
/LCD_DB2: DS1.18 (DB2); also elsewhere on the board
/LCD_DB3: DS1.19 (DB3); also elsewhere on the board
/LCD_DB4: DS1.20 (DB4); also elsewhere on the board
/LCD_DB5: DS1.21 (DB5); also elsewhere on the board
/LCD_DB6: DS1.22 (DB6); also elsewhere on the board
/LCD_DB7: DS1.23 (DB7); also elsewhere on the board
/LCD_DB8: DS1.24 (DB8); also elsewhere on the board
/LCD_DB9: DS1.25 (DB9); also elsewhere on the board
/LCD_DB10: DS1.26 (DB10); also elsewhere on the board
/LCD_DB11: DS1.27 (DB11); also elsewhere on the board
/LCD_DB12: DS1.28 (DB12); also elsewhere on the board
/LCD_DB13: DS1.29 (DB13); also elsewhere on the board
/LCD_DB14: DS1.30 (DB14); also elsewhere on the board
/LCD_DB15: DS1.31 (DB15); also elsewhere on the board
/LCD_DB16: DS1.32 (DB16); also elsewhere on the board
/LCD_DB17: DS1.33 (DB17); also elsewhere on the board
/LCD_DCLK: DS1.12 (DCLK); also elsewhere on the board
/LCD_DE: DS1.13 (DE); also elsewhere on the board
/LCD_HS: DS1.15 (HS); also elsewhere on the board
/LCD_SCL: DS1.10 (SCL); also elsewhere on the board
/LCD_SDA: DS1.9 (SDA); also elsewhere on the board
/LCD_VS: DS1.14 (VS); also elsewhere on the board
/LEDA: DS1.1 (LEDA); also elsewhere on the board
/LEDK: DS1.2 (LEDK1), DS1.3 (LEDK2); also elsewhere on the board
/RP2040/DEBUG_UART_RX: J2.3; also elsewhere on the board
/RP2040/DEBUG_UART_TX: J2.5; also elsewhere on the board
/RP2040/SWCLK: J2.2; also elsewhere on the board
/RP2040/SWD: J2.4; also elsewhere on the board
/SHIELD: C1.2, J1.S1 (SHIELD), J3.SH, J3.SH1 (SH), J3.SH2 (SH), J3.SH3 (SH), R2.2
/TP_INT: DS1.35 (TP_INT); also elsewhere on the board
/TP_RST: DS1.38 (TP_RST); also elsewhere on the board
/TP_SCL: DS1.37 (TP_SCL); also elsewhere on the board
/TP_SDA: DS1.36 (TP_SDA); also elsewhere on the board
/USB_D+: J1.A6 (D+), J1.B6 (D+); also elsewhere on the board
/USB_D-: J1.A7 (D-), J1.B7 (D-); also elsewhere on the board
/~LCD_RST: DS1.6 (~RST); also elsewhere on the board
GND: C1.1, DS1.4 (GND), DS1.34 (GND), DS1.40 (GND), DS1.S1 (GND), DS1.S2 (GND), J1.A1 (GND), J1.A12 (GND), J1.B1 (GND), J1.B12 (GND), J2.6, J3.2 (D2S), J3.5 (D1S), J3.8 (D0S), J3.11 (CKS), J3.14 (UTILITY/HEAC+), J3.17 (GND), R1.2, R2.1, R3.2; also elsewhere on the board

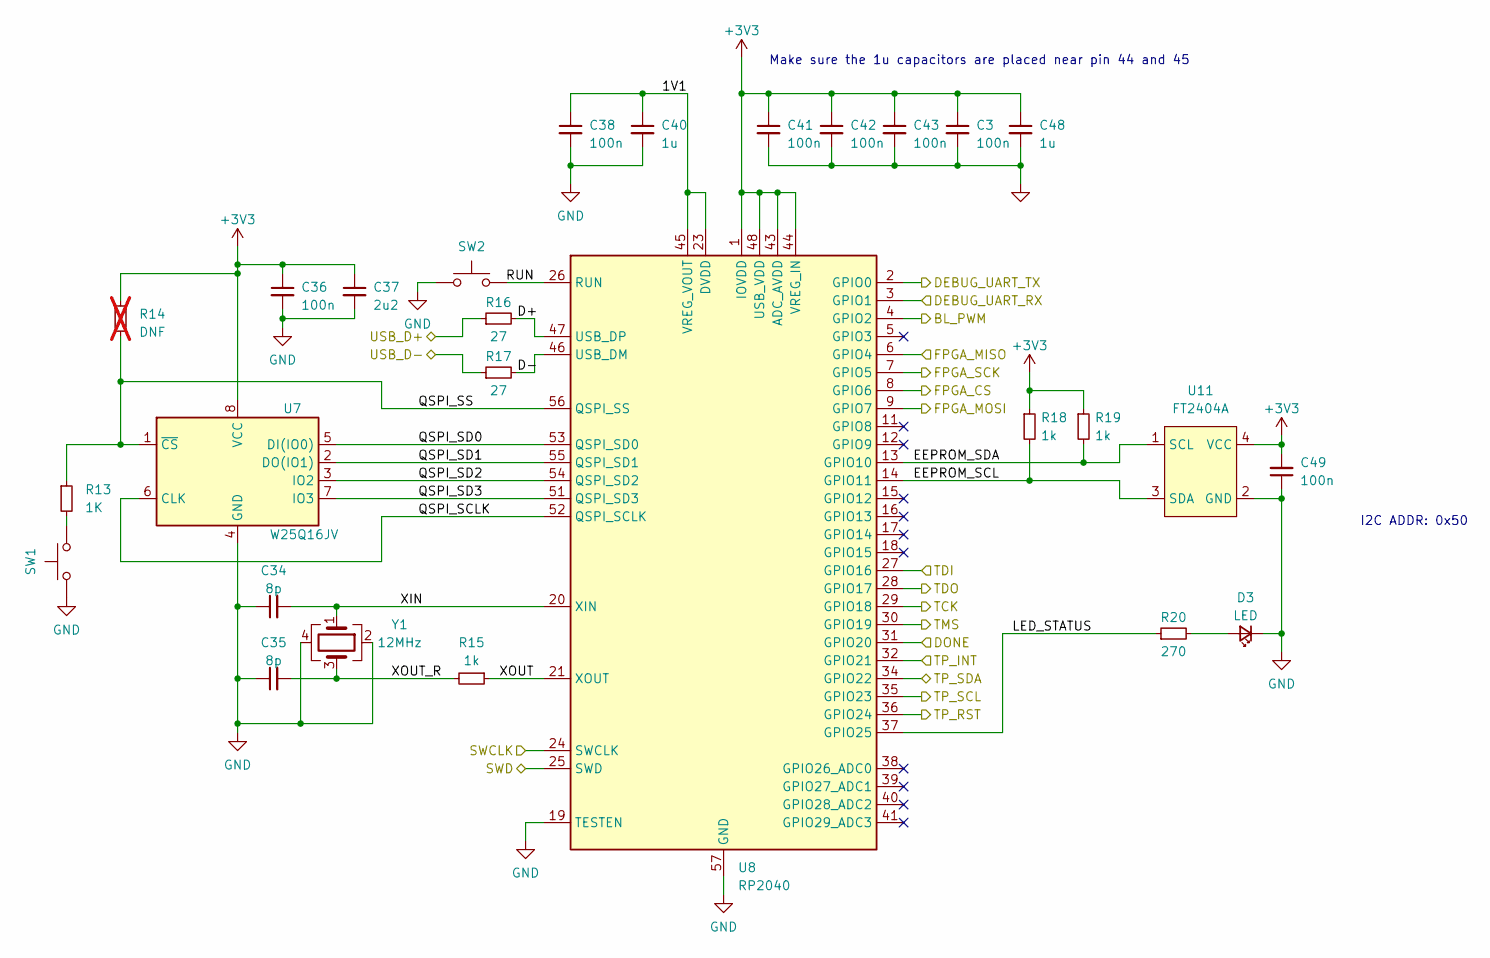
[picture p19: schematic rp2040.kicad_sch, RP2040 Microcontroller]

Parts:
C3, C36, C38, C41, C42, C43, C49: 100n; C_0402_1005Metric
C34, C35: 8p; C_0402_1005Metric
C37: 2u2; C_0402_1005Metric
C40, C48: 1u; C_0402_1005Metric
D3: LED; D_0805_2012Metric
R13: 1K; R_0402_1005Metric
R14: DNF; R_0402_1005Metric; not fitted
R15, R18, R19: 1k; R_0402_1005Metric
R16, R17: 27; R_0402_1005Metric
R20: 270; R_0402_1005Metric
SW1, SW2: DNF; PTS636 SM25J SMTR LFS
U7: W25Q16JV; W25Q16JVUXIQ TR
U8: RP2040; QFN-56-1EP_7x7mm_P0.4mm_EP3.2x3.2mm
U11: FT2404A; SOT-23-5
Y1: 12MHz; ECS120836CKMTR3

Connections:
+3V3: C3.1, C36.1, C37.1, C41.1, C42.1, C43.1, C48.1, C49.2, R14.2, R18.1, R19.1, U7.8 (VCC), U8.1 (IOVDD), U8.10 (IOVDD), U8.22 (IOVDD), U8.33 (IOVDD), U8.42 (IOVDD), U8.43 (ADC_AVDD), U8.44 (VREG_IN), U8.48 (USB_VDD), U8.49 (IOVDD), U11.4 (VCC); also elsewhere on the board
/BL_PWM: U8.4 (GPIO2); also elsewhere on the board
/FPGA_CS: U8.8 (GPIO6); also elsewhere on the board
/FPGA_MISO: U8.6 (GPIO4); also elsewhere on the board
/FPGA_MOSI: U8.9 (GPIO7); also elsewhere on the board
/FPGA_SCK: U8.7 (GPIO5); also elsewhere on the board
/RP2040/1V1: C38.1, C40.1, U8.23 (DVDD), U8.45 (VREG_VOUT), U8.50 (DVDD)
/RP2040/D+: R16.2, U8.47 (USB_DP)
/RP2040/D-: R17.2, U8.46 (USB_DM)
/RP2040/DEBUG_UART_RX: U8.3 (GPIO1); also elsewhere on the board
/RP2040/DEBUG_UART_TX: U8.2 (GPIO0); also elsewhere on the board
/RP2040/DONE: U8.31 (GPIO20)
/RP2040/EEPROM_SCL: R18.2, U8.14 (GPIO11), U11.3 (SDA)
/RP2040/EEPROM_SDA: R19.2, U8.13 (GPIO10), U11.1 (SCL)
/RP2040/LED_STATUS: R20.1, U8.37 (GPIO25)
/RP2040/QSPI_SCLK: U7.6 (CLK), U8.52 (QSPI_SCLK)
/RP2040/QSPI_SD0: U7.5 (DI(IO0)), U8.53 (QSPI_SD0)
/RP2040/QSPI_SD1: U7.2 (DO(IO1)), U8.55 (QSPI_SD1)
/RP2040/QSPI_SD2: U7.3 (IO2), U8.54 (QSPI_SD2)
/RP2040/QSPI_SD3: U7.7 (IO3), U8.51 (QSPI_SD3)
/RP2040/QSPI_SS: R13.1, R14.1, U7.1 (~CS), U8.56 (QSPI_SS)
/RP2040/RUN: SW2.2, U8.26 (RUN)
/RP2040/SWCLK: U8.24 (SWCLK); also elsewhere on the board
/RP2040/SWD: U8.25 (SWD); also elsewhere on the board
/RP2040/XIN: C34.2, U8.20 (XIN), Y1.1
/RP2040/XOUT: R15.1, U8.21 (XOUT)
/RP2040/XOUT_R: C35.2, R15.2, Y1.3
/TCK: U8.29 (GPIO18); also elsewhere on the board
/TDI: U8.27 (GPIO16); also elsewhere on the board
/TDO: U8.28 (GPIO17); also elsewhere on the board
/TMS: U8.30 (GPIO19); also elsewhere on the board
/TP_INT: U8.32 (GPIO21); also elsewhere on the board
/TP_RST: U8.36 (GPIO24); also elsewhere on the board
/TP_SCL: U8.35 (GPIO23); also elsewhere on the board
/TP_SDA: U8.34 (GPIO22); also elsewhere on the board
/USB_D+: R16.1; also elsewhere on the board
/USB_D-: R17.1; also elsewhere on the board
GND: C3.2, C34.1, C35.1, C36.2, C37.2, C38.2, C40.2, C41.2, C42.2, C43.2, C48.2, C49.1, D3.1 (K), SW1.1, SW2.1, U7.4 (GND), U7.9 (GND), U8.19 (TESTEN), U8.57 (GND), U11.2 (GND), Y1.2, Y1.4; also elsewhere on the board
unnamed: D3.2 (A), R20.2
unnamed: R13.2, SW1.2

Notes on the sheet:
I2C ADDR: 0x50
Make sure the 1u capacitors are placed near pin 44 and 45

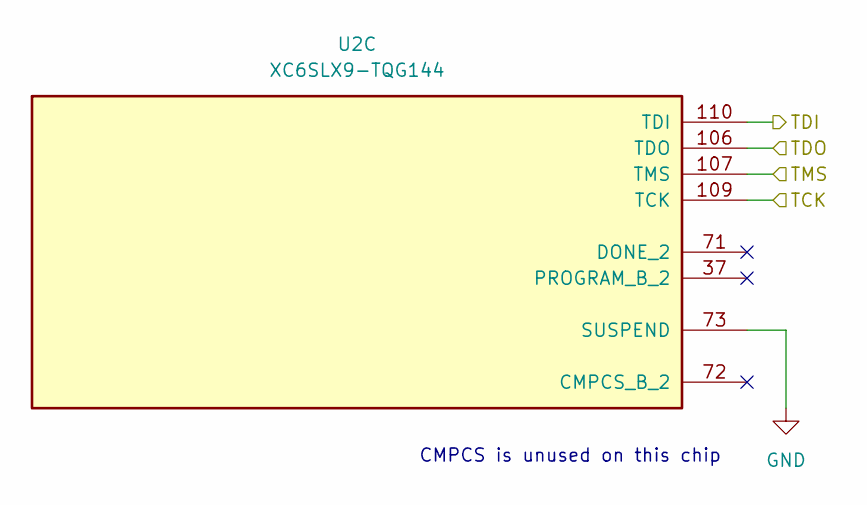
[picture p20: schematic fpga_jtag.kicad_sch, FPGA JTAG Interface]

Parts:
U2: XC6SLX9-TQG144; TQFP-144_20x20mm_P0.5mm

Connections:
/TCK: U2.109 (TCK); also elsewhere on the board
/TDI: U2.110 (TDI); also elsewhere on the board
/TDO: U2.106 (TDO); also elsewhere on the board
/TMS: U2.107 (TMS); also elsewhere on the board
GND: U2.73 (SUSPEND); also elsewhere on the board

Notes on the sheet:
CMPCS is unused on this chip

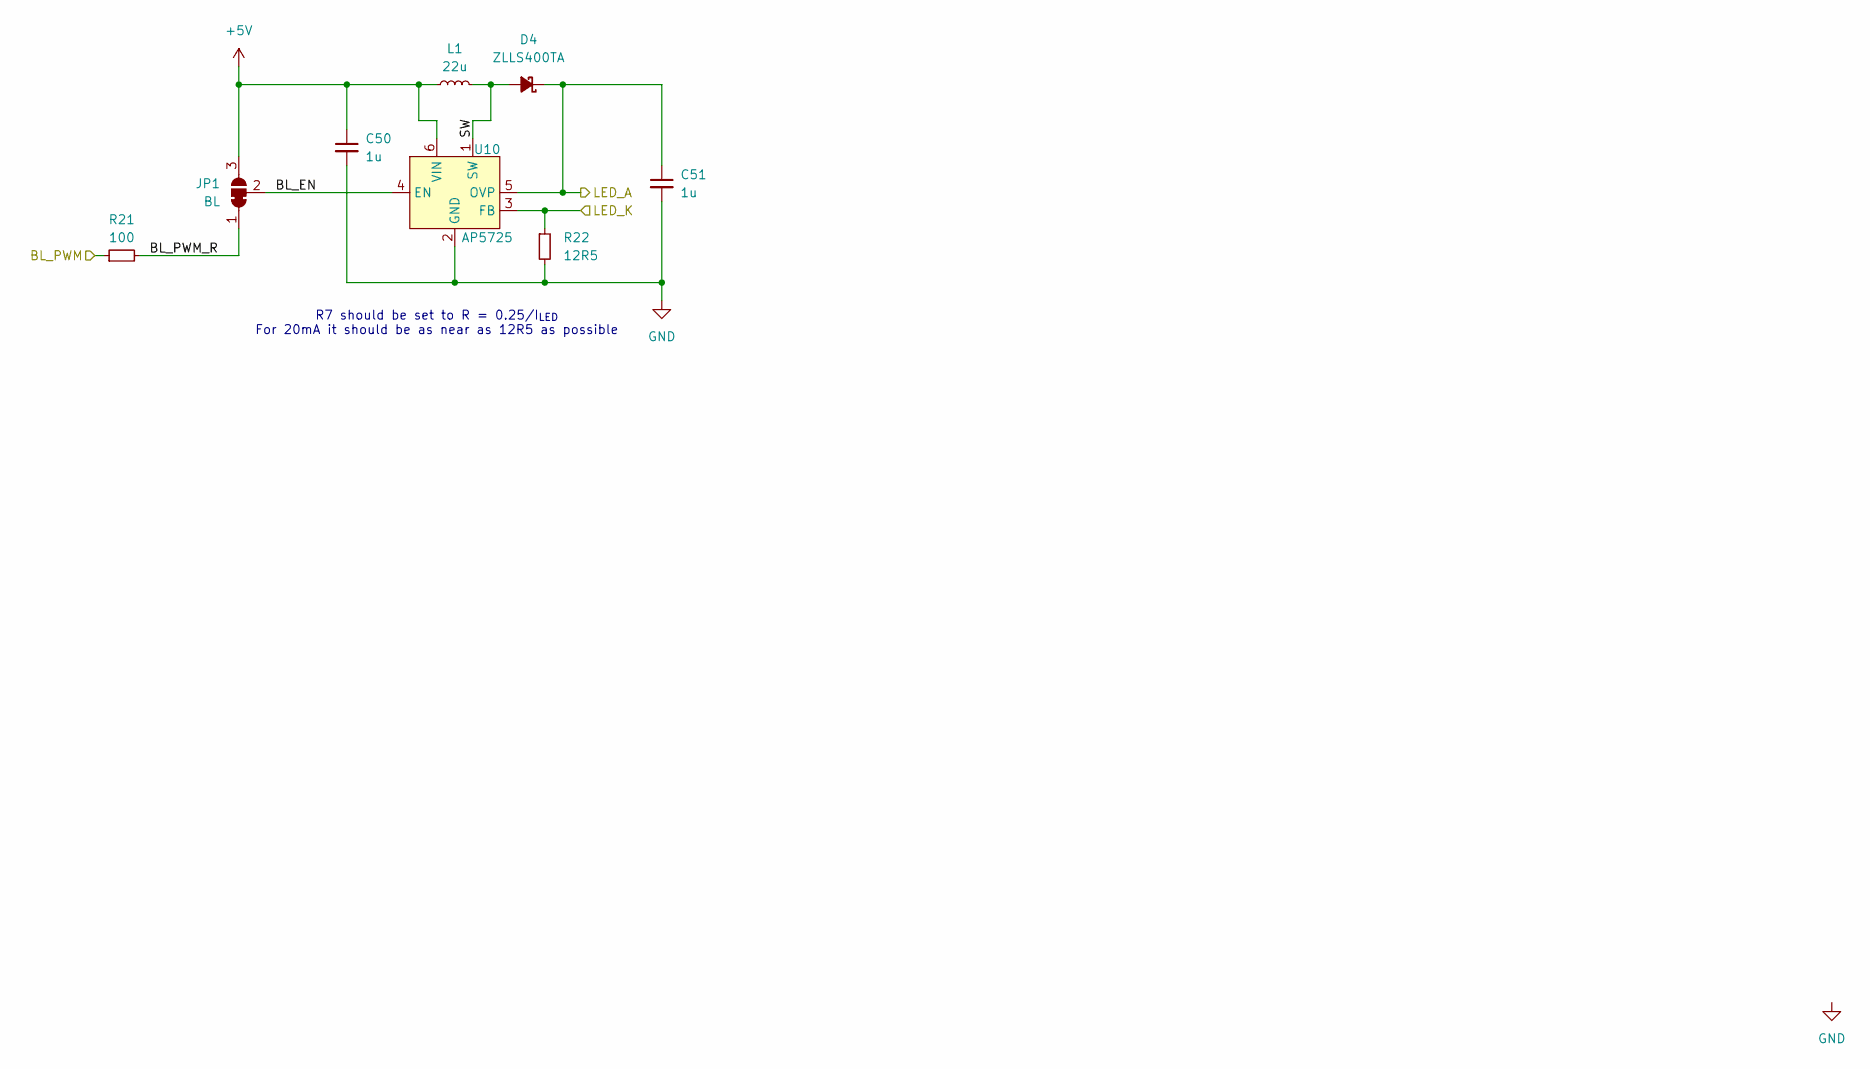
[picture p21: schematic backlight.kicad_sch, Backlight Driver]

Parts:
C50: 1u; C_0402_1005Metric
C51: 1u; C_0603_1608Metric
D4: ZLLS400TA; D_SOD-323
JP1: BL; SolderJumper-3_P1.3mm_Bridged12_RoundedPad1.0x1.5mm
L1: 22u; XRNR4012
R21: 100; R_0402_1005Metric
R22: 12R5; R_0603_1608Metric
U10: AP5725; SOT-23-6

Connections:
+5V: C50.1, JP1.3 (B), L1.1, U10.6 (VIN); also elsewhere on the board
/BL_PWM: R21.1; also elsewhere on the board
/Backlight/BL_EN: JP1.2 (C), U10.4 (EN)
/Backlight/BL_PWM_R: JP1.1 (A), R21.2
/Backlight/SW: D4.2 (A), L1.2, U10.1 (SW)
/LEDA: C51.1, D4.1 (K), U10.5 (OVP); also elsewhere on the board
/LEDK: R22.1, U10.3 (FB); also elsewhere on the board
GND: C50.2, C51.2, R22.2, U10.2 (GND); also elsewhere on the board

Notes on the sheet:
R7 should be set to R = 0.25/I_{LED} For 20mA it should be as near as 12R5 as possible

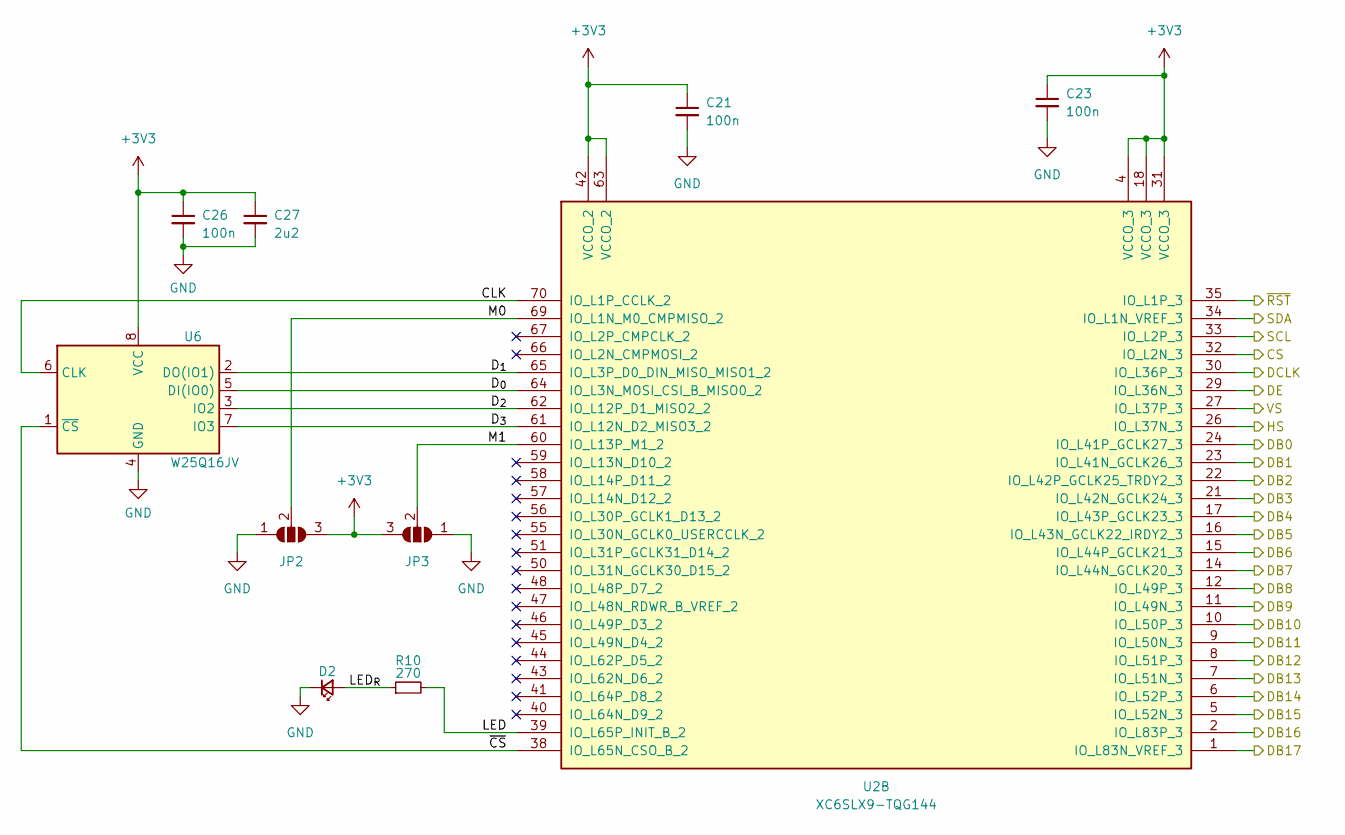
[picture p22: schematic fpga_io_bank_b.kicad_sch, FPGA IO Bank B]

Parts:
C21, C23, C26: 100n; C_0402_1005Metric
C27: 2u2; C_0402_1005Metric
D2: LED; D_0805_2012Metric
JP2, JP3: SolderJumper_3_Open; SolderJumper-3_P1.3mm_Open_RoundedPad1.0x1.5mm
R10: 270; R_0402_1005Metric
U2: XC6SLX9-TQG144; TQFP-144_20x20mm_P0.5mm
U6: W25Q16JV; W25Q16JVUXIQ TR

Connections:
+3V3: C21.1, C23.1, C26.1, C27.1, JP2.3 (B), JP3.3 (B), U2.4 (VCCO_3), U2.18 (VCCO_3), U2.31 (VCCO_3), U2.42 (VCCO_2), U2.63 (VCCO_2), U6.8 (VCC); also elsewhere on the board
/FPGA IO Bank B/CLK: U2.70 (IO_L1P_CCLK_2), U6.6 (CLK)
/FPGA IO Bank B/D_{0}: U2.64 (IO_L3N_MOSI_CSI_B_MISO0_2), U6.5 (DI(IO0))
/FPGA IO Bank B/D_{1}: U2.65 (IO_L3P_D0_DIN_MISO_MISO1_2), U6.2 (DO(IO1))
/FPGA IO Bank B/D_{2}: U2.62 (IO_L12P_D1_MISO2_2), U6.3 (IO2)
/FPGA IO Bank B/D_{3}: U2.61 (IO_L12N_D2_MISO3_2), U6.7 (IO3)
/FPGA IO Bank B/LED: R10.2, U2.39 (IO_L65P_INIT_B_2)
/FPGA IO Bank B/LED_{R}: D2.2 (A), R10.1
/FPGA IO Bank B/M0: JP2.2 (C), U2.69 (IO_L1N_M0_CMPMISO_2)
/FPGA IO Bank B/M1: JP3.2 (C), U2.60 (IO_L13P_M1_2)
/FPGA IO Bank B/~CS: U2.38 (IO_L65N_CSO_B_2), U6.1 (~CS)
/LCD_CS: U2.32 (IO_L2N_3); also elsewhere on the board
/LCD_DB0: U2.24 (IO_L41P_GCLK27_3); also elsewhere on the board
/LCD_DB1: U2.23 (IO_L41N_GCLK26_3); also elsewhere on the board
/LCD_DB2: U2.22 (IO_L42P_GCLK25_TRDY2_3); also elsewhere on the board
/LCD_DB3: U2.21 (IO_L42N_GCLK24_3); also elsewhere on the board
/LCD_DB4: U2.17 (IO_L43P_GCLK23_3); also elsewhere on the board
/LCD_DB5: U2.16 (IO_L43N_GCLK22_IRDY2_3); also elsewhere on the board
/LCD_DB6: U2.15 (IO_L44P_GCLK21_3); also elsewhere on the board
/LCD_DB7: U2.14 (IO_L44N_GCLK20_3); also elsewhere on the board
/LCD_DB8: U2.12 (IO_L49P_3); also elsewhere on the board
/LCD_DB9: U2.11 (IO_L49N_3); also elsewhere on the board
/LCD_DB10: U2.10 (IO_L50P_3); also elsewhere on the board
/LCD_DB11: U2.9 (IO_L50N_3); also elsewhere on the board
/LCD_DB12: U2.8 (IO_L51P_3); also elsewhere on the board
/LCD_DB13: U2.7 (IO_L51N_3); also elsewhere on the board
/LCD_DB14: U2.6 (IO_L52P_3); also elsewhere on the board
/LCD_DB15: U2.5 (IO_L52N_3); also elsewhere on the board
/LCD_DB16: U2.2 (IO_L83P_3); also elsewhere on the board
/LCD_DB17: U2.1 (IO_L83N_VREF_3); also elsewhere on the board
/LCD_DCLK: U2.30 (IO_L36P_3); also elsewhere on the board
/LCD_DE: U2.29 (IO_L36N_3); also elsewhere on the board
/LCD_HS: U2.26 (IO_L37N_3); also elsewhere on the board
/LCD_SCL: U2.33 (IO_L2P_3); also elsewhere on the board
/LCD_SDA: U2.34 (IO_L1N_VREF_3); also elsewhere on the board
/LCD_VS: U2.27 (IO_L37P_3); also elsewhere on the board
/~LCD_RST: U2.35 (IO_L1P_3); also elsewhere on the board
GND: C21.2, C23.2, C26.2, C27.2, D2.1 (K), JP2.1 (A), JP3.1 (A), U6.4 (GND), U6.9 (GND); also elsewhere on the board

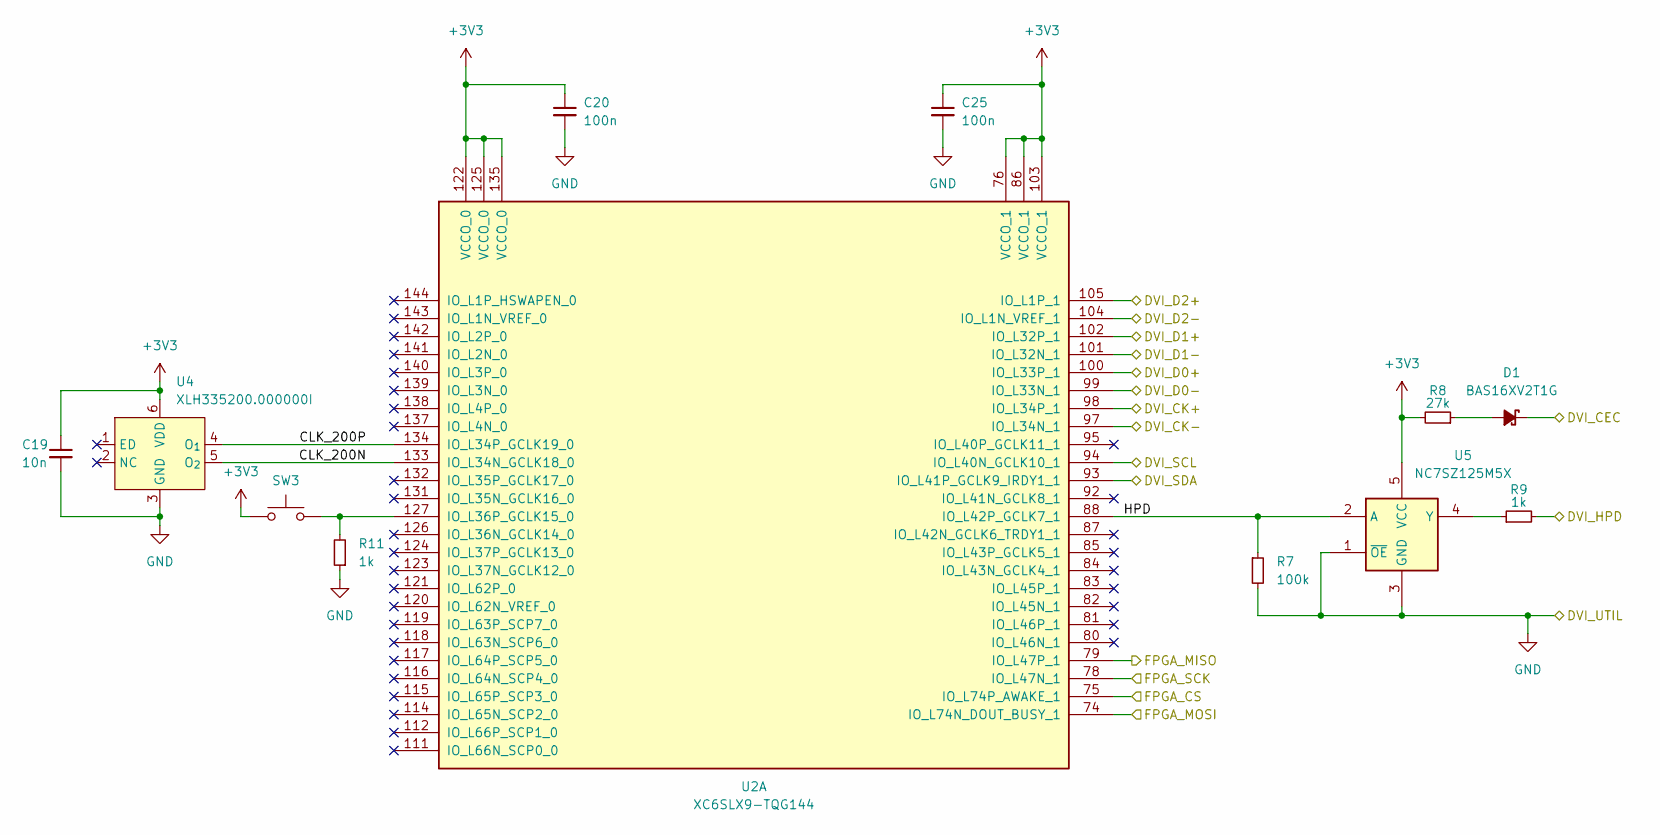
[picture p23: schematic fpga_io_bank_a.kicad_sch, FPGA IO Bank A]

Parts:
C19: 10n; C_0402_1005Metric
C20, C25: 100n; C_0402_1005Metric
D1: BAS16XV2T1G; D_SOD-523
R7: 100k; R_0402_1005Metric
R8: 27k; R_0402_1005Metric
R9, R11: 1k; R_0402_1005Metric
SW3: DNF; PTS636 SM25J SMTR LFS
U2: XC6SLX9-TQG144; TQFP-144_20x20mm_P0.5mm
U4: XLH335200.000000I
U5: NC7SZ125M5X; SOT-23-5

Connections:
+3V3: C19.1, C20.1, C25.1, R8.2, SW3.1, U2.76 (VCCO_1), U2.86 (VCCO_1), U2.103 (VCCO_1), U2.122 (VCCO_0), U2.125 (VCCO_0), U2.135 (VCCO_0), U4.6 (VDD), U5.5 (VCC); also elsewhere on the board
/DVI_CEC: D1.1 (K); also elsewhere on the board
/DVI_CK+: U2.98 (IO_L34P_1); also elsewhere on the board
/DVI_CK-: U2.97 (IO_L34N_1); also elsewhere on the board
/DVI_D0+: U2.100 (IO_L33P_1); also elsewhere on the board
/DVI_D0-: U2.99 (IO_L33N_1); also elsewhere on the board
/DVI_D1+: U2.102 (IO_L32P_1); also elsewhere on the board
/DVI_D1-: U2.101 (IO_L32N_1); also elsewhere on the board
/DVI_D2+: U2.105 (IO_L1P_1); also elsewhere on the board
/DVI_D2-: U2.104 (IO_L1N_VREF_1); also elsewhere on the board
/DVI_HPD: R9.2; also elsewhere on the board
/DVI_SCL: U2.94 (IO_L40N_GCLK10_1); also elsewhere on the board
/DVI_SDA: U2.93 (IO_L41P_GCLK9_IRDY1_1); also elsewhere on the board
/FPGA IO Bank A/CLK_200N: U2.133 (IO_L34N_GCLK18_0), U4.5 (O_{2})
/FPGA IO Bank A/CLK_200P: U2.134 (IO_L34P_GCLK19_0), U4.4 (O_{1})
/FPGA IO Bank A/HPD: R7.1, U2.88 (IO_L42P_GCLK7_1), U5.2 (A)
/FPGA_CS: U2.75 (IO_L74P_AWAKE_1); also elsewhere on the board
/FPGA_MISO: U2.79 (IO_L47P_1); also elsewhere on the board
/FPGA_MOSI: U2.74 (IO_L74N_DOUT_BUSY_1); also elsewhere on the board
/FPGA_SCK: U2.78 (IO_L47N_1); also elsewhere on the board
GND: C19.2, C20.2, C25.2, R7.2, R11.1, U4.3 (GND), U5.1 (~OE), U5.3 (GND); also elsewhere on the board
unnamed: D1.2 (A), R8.1
unnamed: R11.2, SW3.2, U2.127 (IO_L36P_GCLK15_0)
unnamed: R9.1, U5.4 (Y)

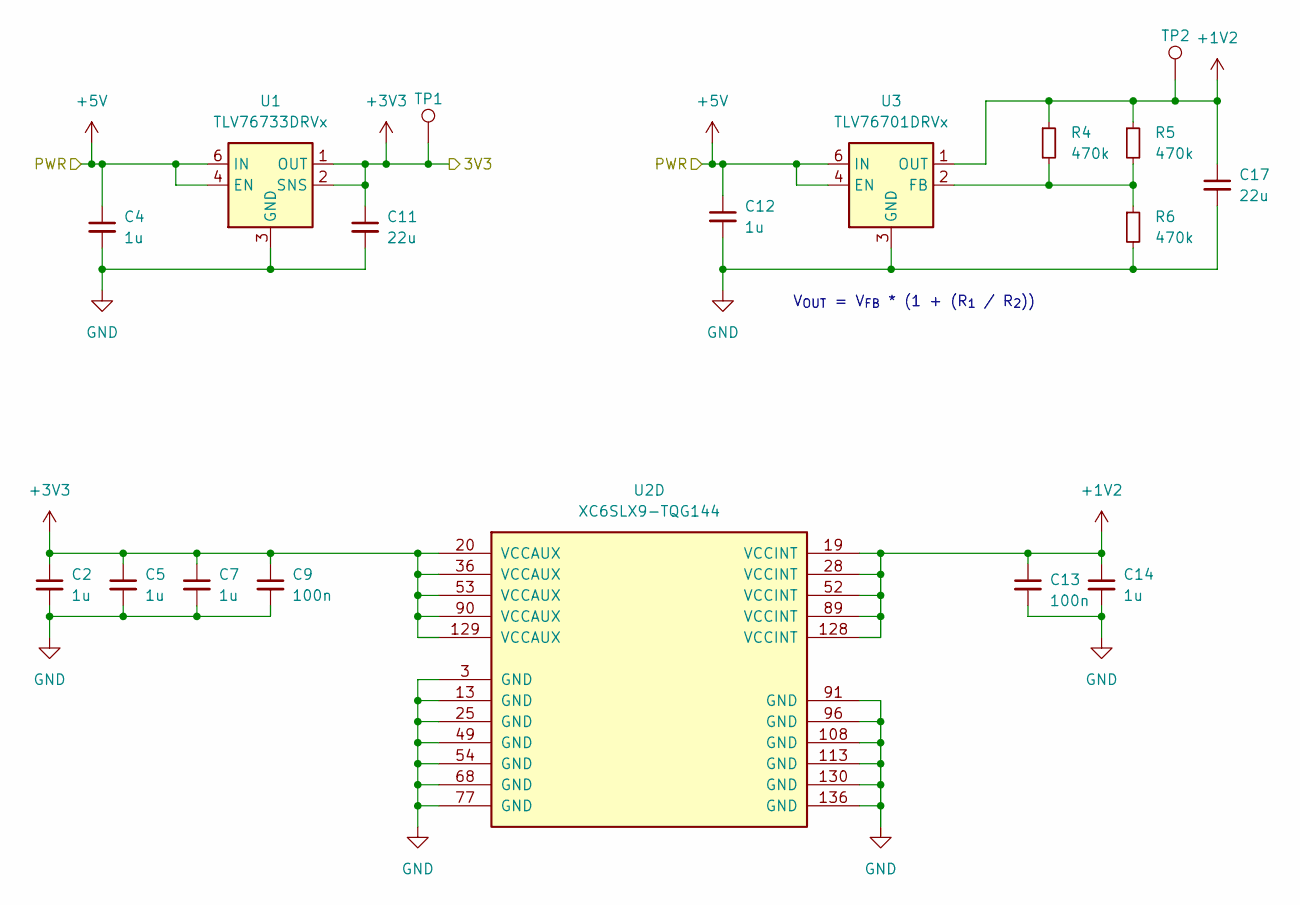
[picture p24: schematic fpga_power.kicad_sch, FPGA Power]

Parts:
C2, C4, C5, C7, C12, C14: 1u; C_0402_1005Metric
C9, C13: 100n; C_0402_1005Metric
C11, C17: 22u; C_0603_1608Metric
R4, R5, R6: 470k; R_0402_1005Metric
TP1, TP2: TestPoint; TestPoint_Pad_D1.0mm
U1: TLV76733DRVx; WSON-6-1EP_2x2mm_P0.65mm_EP1x1.6mm_ThermalVias
U2: XC6SLX9-TQG144; TQFP-144_20x20mm_P0.5mm
U3: TLV76701DRVx; WSON-6-1EP_2x2mm_P0.65mm_EP1x1.6mm_ThermalVias

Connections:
+1V2: C13.1, C14.1, C17.1, R4.1, R5.1, TP2.1, U2.19 (VCCINT), U2.28 (VCCINT), U2.52 (VCCINT), U2.89 (VCCINT), U2.128 (VCCINT), U3.1 (OUT)
+3V3: C2.1, C5.1, C7.1, C9.1, C11.1, TP1.1, U1.1 (OUT), U1.2 (SNS), U2.20 (VCCAUX), U2.36 (VCCAUX), U2.53 (VCCAUX), U2.90 (VCCAUX), U2.129 (VCCAUX); also elsewhere on the board
+5V: C4.1, C12.1, U1.4 (EN), U1.6 (IN), U3.4 (EN), U3.6 (IN); also elsewhere on the board
GND: C2.2, C4.2, C5.2, C7.2, C9.2, C11.2, C12.2, C13.2, C14.2, C17.2, R6.2, U1.3 (GND), U1.5 (GND), U1.7 (PAD), U2.3 (GND), U2.13 (GND), U2.25 (GND), U2.49 (GND), U2.54 (GND), U2.68 (GND), U2.77 (GND), U2.91 (GND), U2.96 (GND), U2.108 (GND), U2.113 (GND), U2.130 (GND), U2.136 (GND), U3.3 (GND), U3.5 (GND), U3.7 (PAD); also elsewhere on the board
unnamed: R4.2, R5.2, R6.1, U3.2 (FB)

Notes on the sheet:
V_{OUT} = V_{FB} * (1 + (R_{1} / R_{2}))

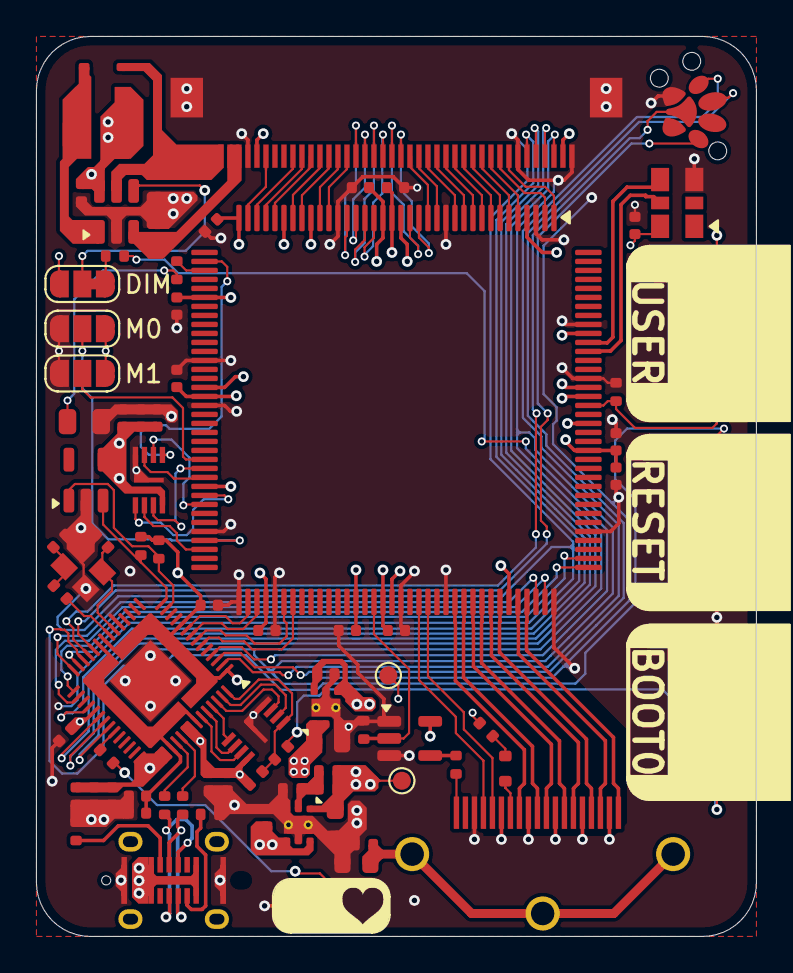
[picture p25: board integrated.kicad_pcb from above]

Board: 4 copper layers, 40.0 x 50.0 mm, 81 parts (0 on the bottom side), 104 nets.

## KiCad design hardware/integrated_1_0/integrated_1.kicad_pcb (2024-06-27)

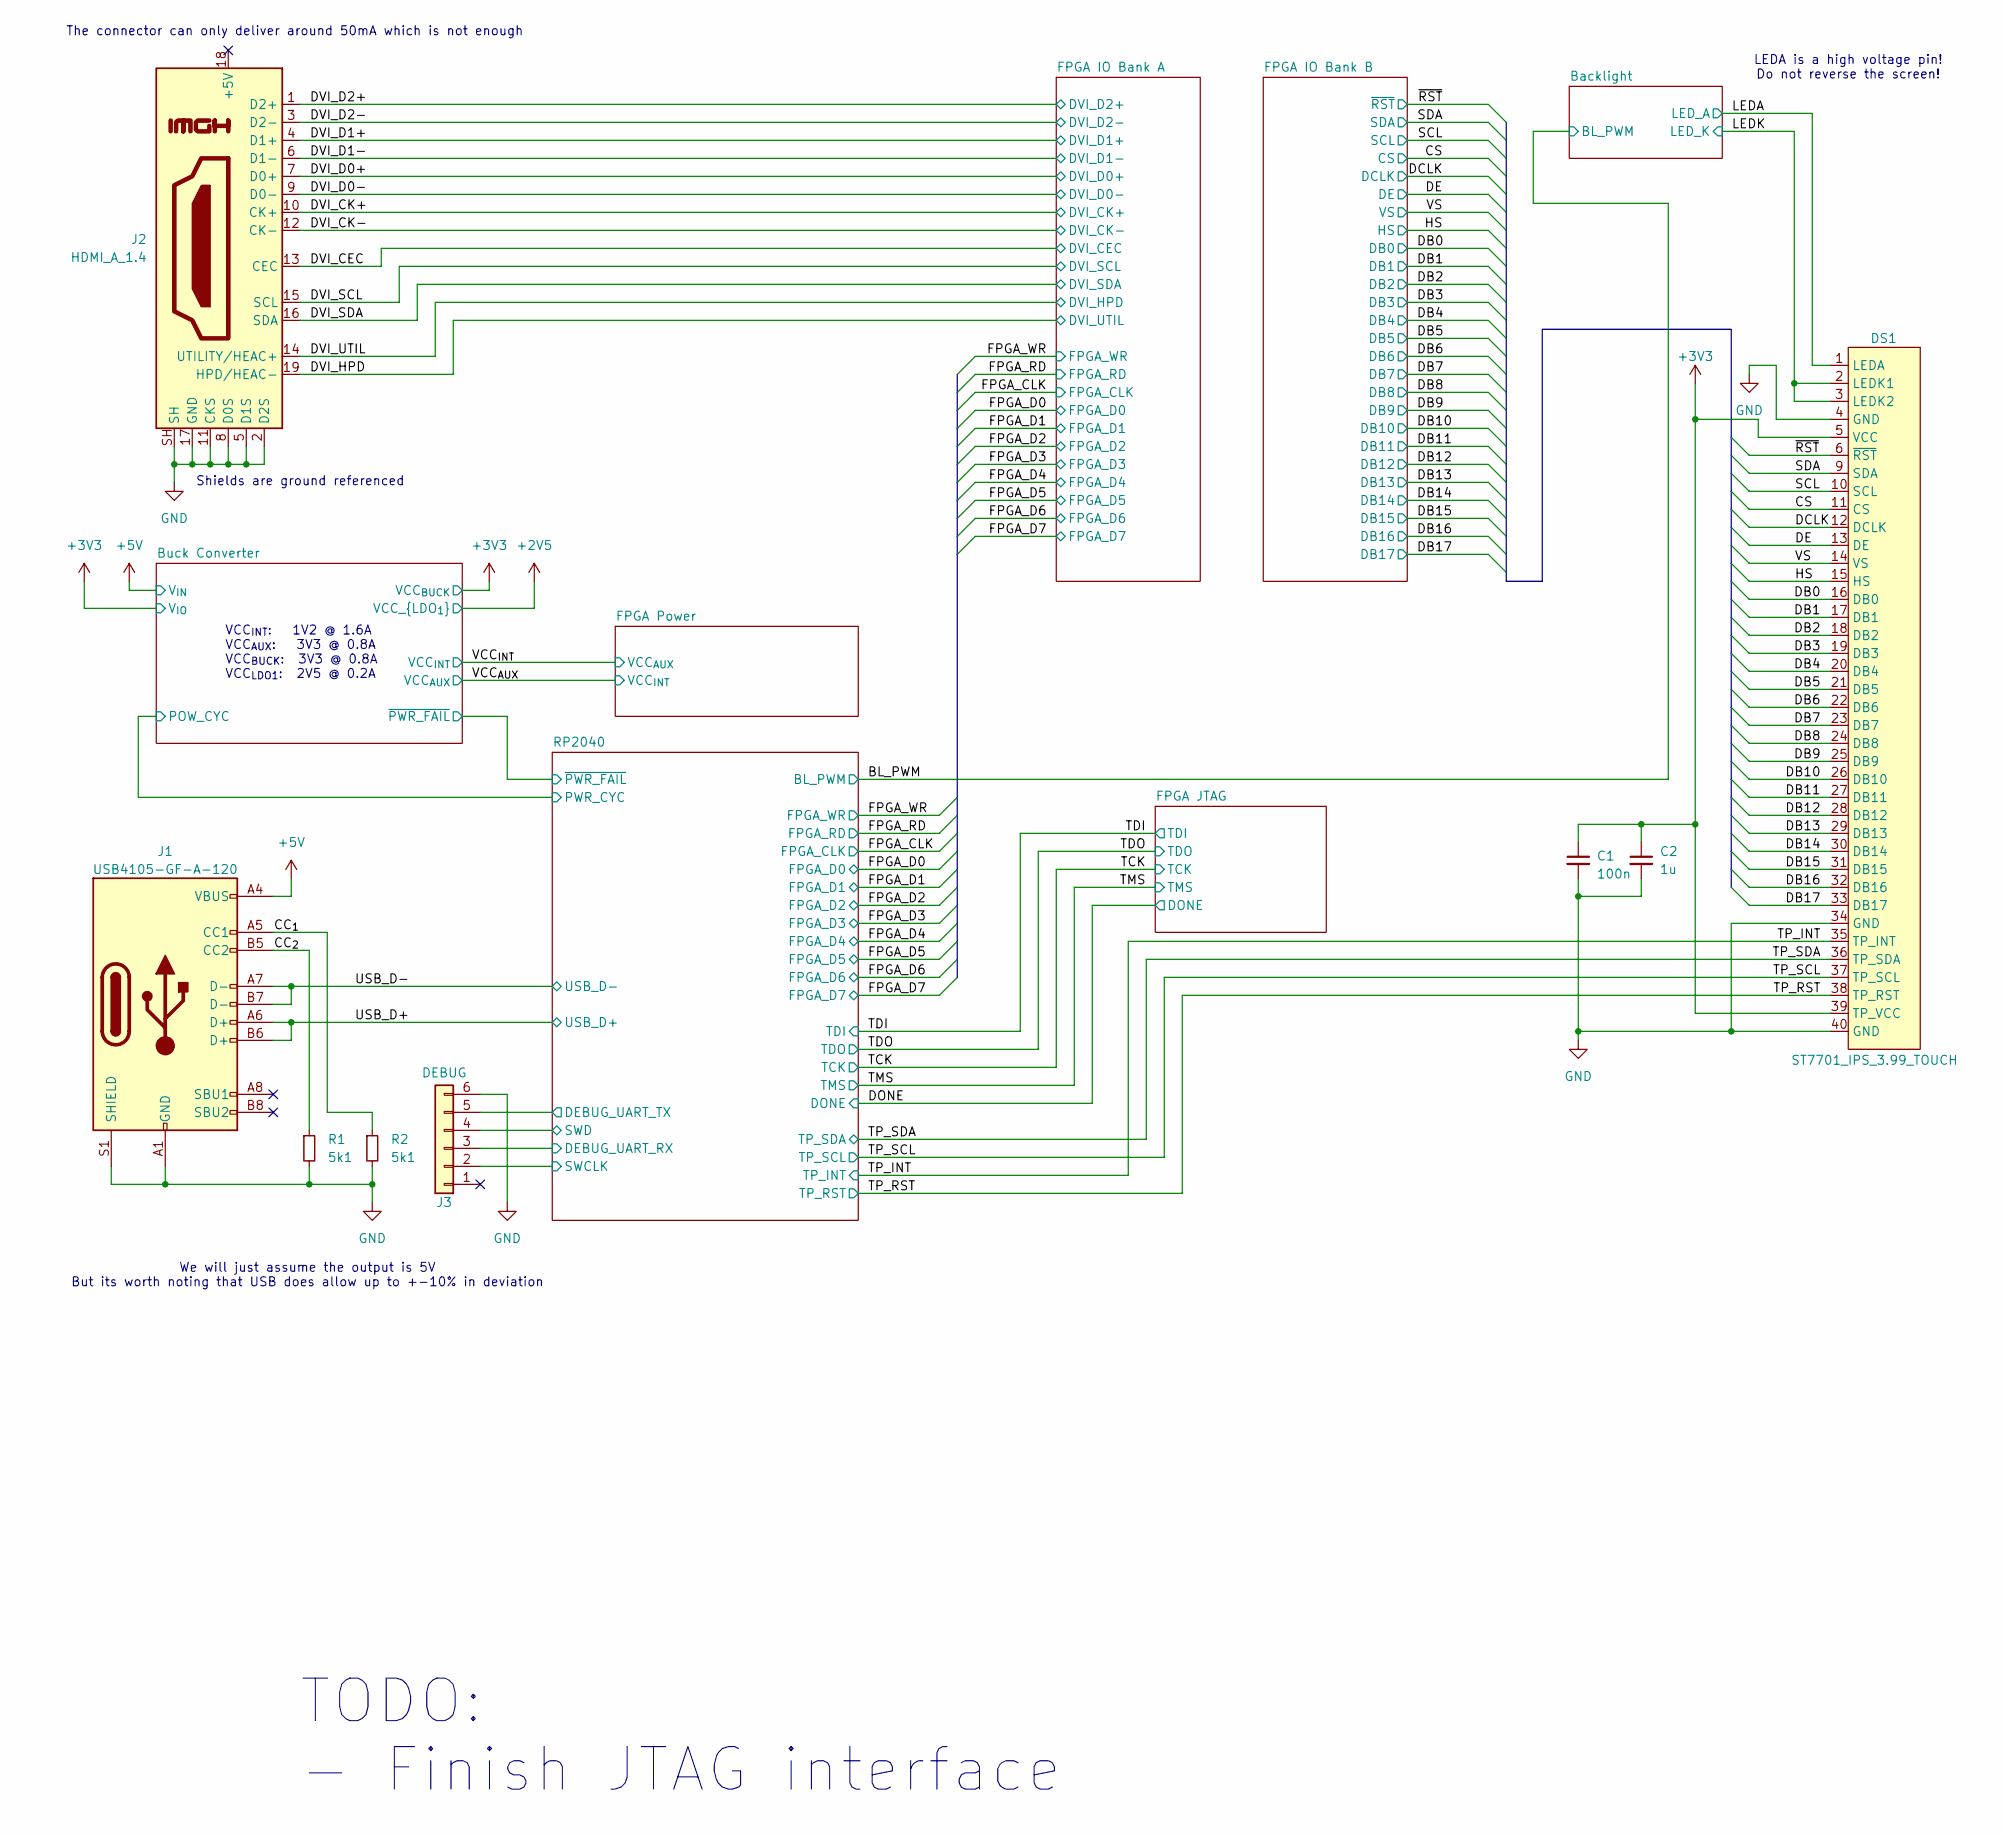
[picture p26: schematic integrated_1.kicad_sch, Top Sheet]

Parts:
C1: 100n; C_0402_1005Metric
C2: 1u; C_0402_1005Metric
DS1: ST7701_IPS_3.99_TOUCH; GCT_FFC2B35-40-G_REVA2_INV
J1: USB4105-GF-A-120; CONN_217182-0001_MOL
J2: HDMI_A_1.4; MOLEX_476591102
J3: DEBUG; Paw-Connect_RevB_TC2030-IDC-NL_2x03_P1.27mm_Vertical
R1, R2: 5k1; R_0402_1005Metric

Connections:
+3V3: C1.1, C2.1, DS1.5 (VCC), DS1.39 (TP_VCC); also elsewhere on the board
+5V: J1.A4 (VBUS), J1.A9 (VBUS), J1.B4 (VBUS), J1.B9 (VBUS); also elsewhere on the board
/CC_{1}: J1.A5 (CC1), R2.1
/CC_{2}: J1.B5 (CC2), R1.1
/CS: DS1.11 (CS); also elsewhere on the board
/DB0: DS1.16 (DB0); also elsewhere on the board
/DB1: DS1.17 (DB1); also elsewhere on the board
/DB2: DS1.18 (DB2); also elsewhere on the board
/DB3: DS1.19 (DB3); also elsewhere on the board
/DB4: DS1.20 (DB4); also elsewhere on the board
/DB5: DS1.21 (DB5); also elsewhere on the board
/DB6: DS1.22 (DB6); also elsewhere on the board
/DB7: DS1.23 (DB7); also elsewhere on the board
/DB8: DS1.24 (DB8); also elsewhere on the board
/DB9: DS1.25 (DB9); also elsewhere on the board
/DB10: DS1.26 (DB10); also elsewhere on the board
/DB11: DS1.27 (DB11); also elsewhere on the board
/DB12: DS1.28 (DB12); also elsewhere on the board
/DB13: DS1.29 (DB13); also elsewhere on the board
/DB14: DS1.30 (DB14); also elsewhere on the board
/DB15: DS1.31 (DB15); also elsewhere on the board
/DB16: DS1.32 (DB16); also elsewhere on the board
/DB17: DS1.33 (DB17); also elsewhere on the board
/DCLK: DS1.12 (DCLK); also elsewhere on the board
/DE: DS1.13 (DE); also elsewhere on the board
/DVI_CEC: J2.13 (CEC); also elsewhere on the board
/DVI_CK+: J2.10 (CK+); also elsewhere on the board
/DVI_CK-: J2.12 (CK-); also elsewhere on the board
/DVI_D0+: J2.7 (D0+); also elsewhere on the board
/DVI_D0-: J2.9 (D0-); also elsewhere on the board
/DVI_D1+: J2.4 (D1+); also elsewhere on the board
/DVI_D1-: J2.6 (D1-); also elsewhere on the board
/DVI_D2+: J2.1 (D2+); also elsewhere on the board
/DVI_D2-: J2.3 (D2-); also elsewhere on the board
/DVI_HPD: J2.19 (HPD/HEAC-); also elsewhere on the board
/DVI_SCL: J2.15 (SCL); also elsewhere on the board
/DVI_SDA: J2.16 (SDA); also elsewhere on the board
/DVI_UTIL: J2.14 (UTILITY/HEAC+); also elsewhere on the board
/HS: DS1.15 (HS); also elsewhere on the board
/LEDA: DS1.1 (LEDA); also elsewhere on the board
/LEDK: DS1.2 (LEDK1), DS1.3 (LEDK2); also elsewhere on the board
/RP2040/DEBUG_UART_RX: J3.3; also elsewhere on the board
/RP2040/DEBUG_UART_TX: J3.5; also elsewhere on the board
/RP2040/SWCLK: J3.2; also elsewhere on the board
/RP2040/SWD: J3.4; also elsewhere on the board
/SCL: DS1.10 (SCL); also elsewhere on the board
/SDA: DS1.9 (SDA); also elsewhere on the board
/TP_INT: DS1.35 (TP_INT); also elsewhere on the board
/TP_RST: DS1.38 (TP_RST); also elsewhere on the board
/TP_SCL: DS1.37 (TP_SCL); also elsewhere on the board
/TP_SDA: DS1.36 (TP_SDA); also elsewhere on the board
/USB_D+: J1.A6 (D+), J1.B6 (D+); also elsewhere on the board
/USB_D-: J1.A7 (D-), J1.B7 (D-); also elsewhere on the board
/VS: DS1.14 (VS); also elsewhere on the board
/~RST: DS1.6 (~RST); also elsewhere on the board
GND: C1.2, C2.2, DS1.4 (GND), DS1.34 (GND), DS1.40 (GND), DS1.S1 (GND), DS1.S2 (GND), J1.A1 (GND), J1.A12 (GND), J1.B1 (GND), J1.B12 (GND), J1.S1 (SHIELD), J2.2 (D2S), J2.5 (D1S), J2.8 (D0S), J2.11 (CKS), J2.17 (GND), J2.SH, J2.SH1 (SH), J2.SH2 (SH), J2.SH3 (SH), J3.6, R1.2, R2.2; also elsewhere on the board

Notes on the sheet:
LEDA is a high voltage pin! Do not reverse the screen!
VCC_{INT}: 1V2 @ 1.6A VCC_{AUX}: 3V3 @ 0.8A VCC_{BUCK}: 3V3 @ 0.8A VCC_{LDO1}: 2V5 @ 0.2A
Shields are ground referenced
We will just assume the output is 5V But its worth noting that USB does allow up to +-10% in deviation
TODO: - Finish JTAG interface
The connector can only deliver around 50mA which is not enough

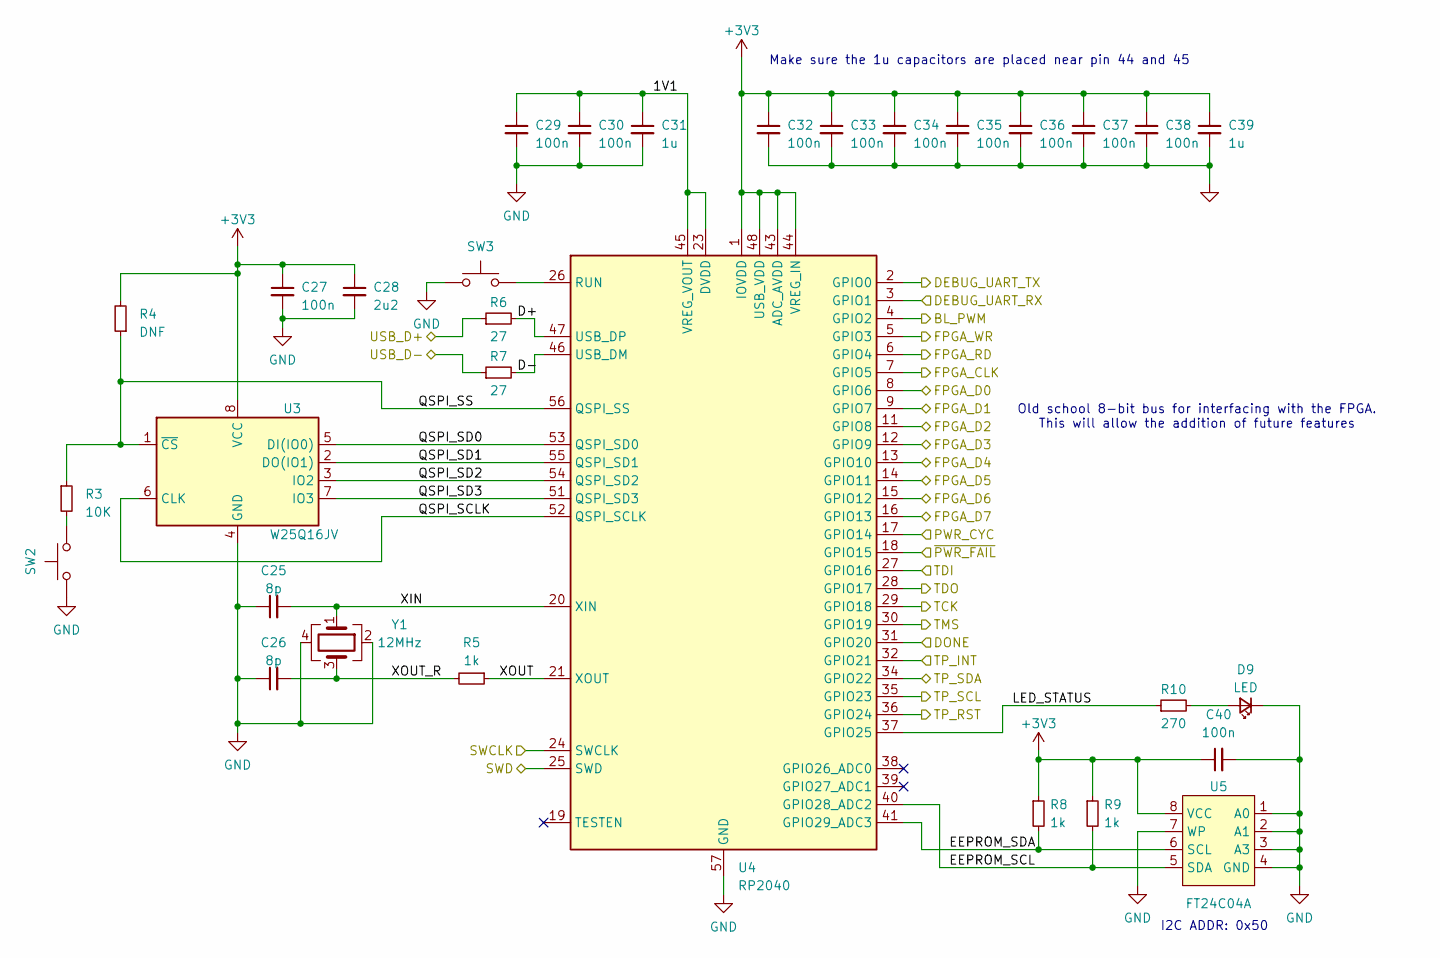
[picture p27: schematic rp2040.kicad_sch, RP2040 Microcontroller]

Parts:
C25, C26: 8p; C_0402_1005Metric
C27, C29, C30, C32, C33, C34, C35, C36, C37, C38, C40: 100n; C_0402_1005Metric
C28: 2u2; C_0603_1608Metric
C31, C39: 1u; C_0402_1005Metric
D9: LED; D_0805_2012Metric
R3: 10K; R_0402_1005Metric
R4: DNF; R_0402_1005Metric
R5, R8, R9: 1k; R_0402_1005Metric
R6, R7: 27; R_0402_1005Metric
R10: 270; R_0402_1005Metric
SW2, SW3: DNF; PTS636 SM25J SMTR LFS
U3: W25Q16JV; W25Q16JVUXIQ TR
U4: RP2040; QFN-56-1EP_7x7mm_P0.4mm_EP3.2x3.2mm
U5: FT24C04A; SOIC-8_3.9x4.9mm_P1.27mm
Y1: 12MHz; ECS120836CKMTR3

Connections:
+3V3: C27.1, C28.1, C32.1, C33.1, C34.1, C35.1, C36.1, C37.1, C38.1, C39.1, C40.1, R4.2, R8.1, R9.1, U3.8 (VCC), U4.1 (IOVDD), U4.10 (IOVDD), U4.22 (IOVDD), U4.33 (IOVDD), U4.42 (IOVDD), U4.43 (ADC_AVDD), U4.44 (VREG_IN), U4.48 (USB_VDD), U4.49 (IOVDD), U5.8 (VCC); also elsewhere on the board
/BL_PWM: U4.4 (GPIO2); also elsewhere on the board
/Buck Converter/EN: U4.17 (GPIO14); also elsewhere on the board
/Buck Converter/~PWR_FAIL: U4.18 (GPIO15); also elsewhere on the board
/DONE: U4.31 (GPIO20); also elsewhere on the board
/FPGA_CLK: U4.7 (GPIO5); also elsewhere on the board
/FPGA_D0: U4.8 (GPIO6); also elsewhere on the board
/FPGA_D1: U4.9 (GPIO7); also elsewhere on the board
/FPGA_D2: U4.11 (GPIO8); also elsewhere on the board
/FPGA_D3: U4.12 (GPIO9); also elsewhere on the board
/FPGA_D4: U4.13 (GPIO10); also elsewhere on the board
/FPGA_D5: U4.14 (GPIO11); also elsewhere on the board
/FPGA_D6: U4.15 (GPIO12); also elsewhere on the board
/FPGA_D7: U4.16 (GPIO13); also elsewhere on the board
/FPGA_RD: U4.6 (GPIO4); also elsewhere on the board
/FPGA_WR: U4.5 (GPIO3); also elsewhere on the board
/RP2040/1V1: C29.1, C30.1, C31.1, U4.23 (DVDD), U4.45 (VREG_VOUT), U4.50 (DVDD)
/RP2040/D+: R6.2, U4.47 (USB_DP)
/RP2040/D-: R7.2, U4.46 (USB_DM)
/RP2040/DEBUG_UART_RX: U4.3 (GPIO1); also elsewhere on the board
/RP2040/DEBUG_UART_TX: U4.2 (GPIO0); also elsewhere on the board
/RP2040/EEPROM_SCL: R9.2, U4.40 (GPIO28_ADC2), U5.5 (SDA)
/RP2040/EEPROM_SDA: R8.2, U4.41 (GPIO29_ADC3), U5.6 (SCL)
/RP2040/LED_STATUS: R10.1, U4.37 (GPIO25)
/RP2040/QSPI_SCLK: U3.6 (CLK), U4.52 (QSPI_SCLK)
/RP2040/QSPI_SD0: U3.5 (DI(IO0)), U4.53 (QSPI_SD0)
/RP2040/QSPI_SD1: U3.2 (DO(IO1)), U4.55 (QSPI_SD1)
/RP2040/QSPI_SD2: U3.3 (IO2), U4.54 (QSPI_SD2)
/RP2040/QSPI_SD3: U3.7 (IO3), U4.51 (QSPI_SD3)
/RP2040/QSPI_SS: R3.1, R4.1, U3.1 (~CS), U4.56 (QSPI_SS)
/RP2040/SWCLK: U4.24 (SWCLK); also elsewhere on the board
/RP2040/SWD: U4.25 (SWD); also elsewhere on the board
/RP2040/XIN: C25.2, U4.20 (XIN), Y1.1
/RP2040/XOUT: R5.1, U4.21 (XOUT)
/RP2040/XOUT_R: C26.2, R5.2, Y1.3
/TCK: U4.29 (GPIO18); also elsewhere on the board
/TDI: U4.27 (GPIO16); also elsewhere on the board
/TDO: U4.28 (GPIO17); also elsewhere on the board
/TMS: U4.30 (GPIO19); also elsewhere on the board
/TP_INT: U4.32 (GPIO21); also elsewhere on the board
/TP_RST: U4.36 (GPIO24); also elsewhere on the board
/TP_SCL: U4.35 (GPIO23); also elsewhere on the board
/TP_SDA: U4.34 (GPIO22); also elsewhere on the board
/USB_D+: R6.1; also elsewhere on the board
/USB_D-: R7.1; also elsewhere on the board
GND: C25.1, C26.1, C27.2, C28.2, C29.2, C30.2, C31.2, C32.2, C33.2, C34.2, C35.2, C36.2, C37.2, C38.2, C39.2, C40.2, D9.1 (K), SW2.1, SW3.1, U3.4 (GND), U3.9 (GND), U4.57 (GND), U5.1 (A0), U5.2 (A1), U5.3 (A3), U5.4 (GND), U5.7 (WP), Y1.2, Y1.4; also elsewhere on the board
unnamed: D9.2 (A), R10.2
unnamed: R3.2, SW2.2
unnamed: SW3.2, U4.26 (RUN)

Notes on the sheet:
I2C ADDR: 0x50
Old school 8-bit bus for interfacing with the FPGA. This will allow the addition of future features
Make sure the 1u capacitors are placed near pin 44 and 45

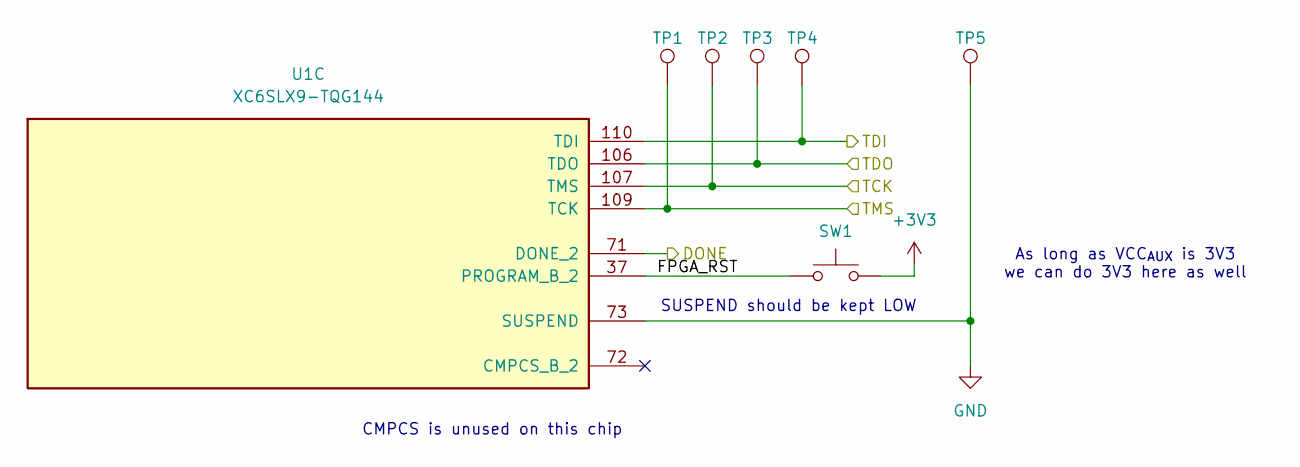
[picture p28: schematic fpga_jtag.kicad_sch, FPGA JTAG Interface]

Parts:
SW1: DNF; PTS636 SM25J SMTR LFS
TP1, TP2, TP3, TP4, TP5: TestPoint; TestPoint_Pad_D1.0mm
U1: XC6SLX9-TQG144; TQFP-144_20x20mm_P0.5mm

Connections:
+3V3: SW1.2; also elsewhere on the board
/DONE: U1.71 (DONE_2); also elsewhere on the board
/FPGA JTAG/FPGA_RST: SW1.1, U1.37 (PROGRAM_B_2)
/TCK: TP2.1, U1.107 (TMS); also elsewhere on the board
/TDI: TP4.1, U1.110 (TDI); also elsewhere on the board
/TDO: TP3.1, U1.106 (TDO); also elsewhere on the board
/TMS: TP1.1, U1.109 (TCK); also elsewhere on the board
GND: TP5.1, U1.73 (SUSPEND); also elsewhere on the board

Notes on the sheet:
SUSPEND should be kept LOW
CMPCS is unused on this chip
As long as VCC_{AUX} is 3V3 we can do 3V3 here as well

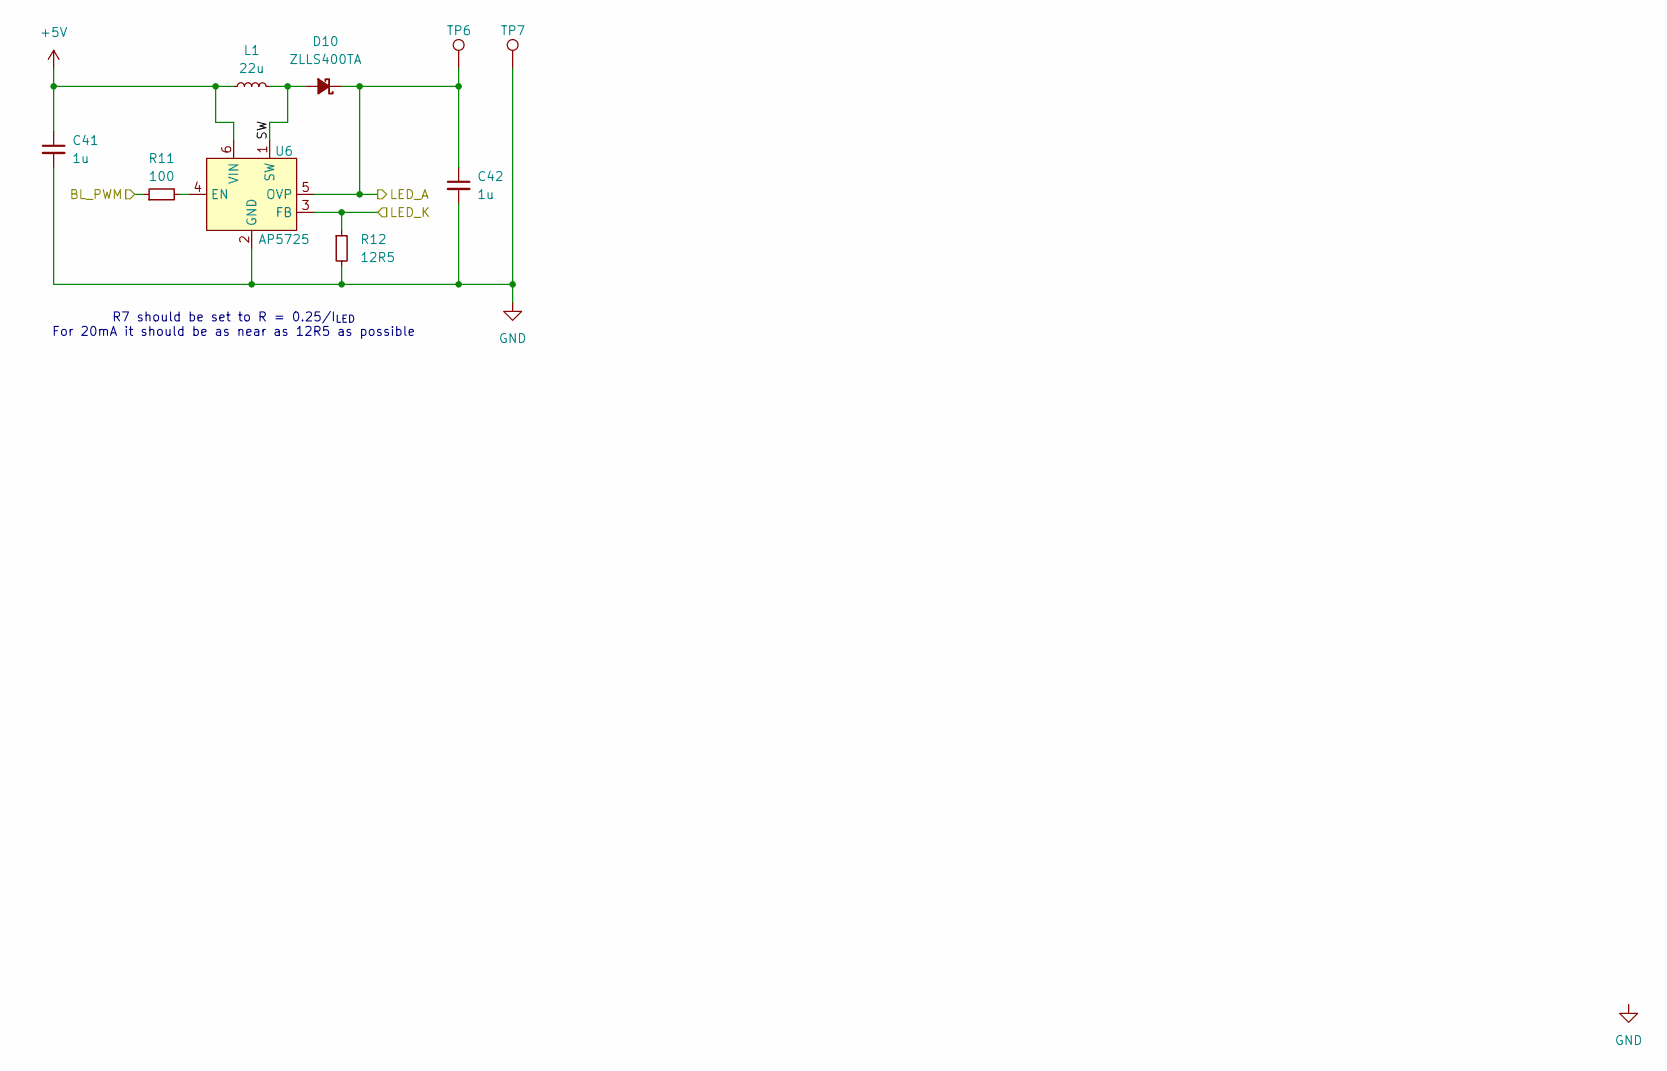
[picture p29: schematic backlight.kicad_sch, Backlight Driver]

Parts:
C41: 1u; C_0402_1005Metric
C42: 1u; C_0603_1608Metric
D10: ZLLS400TA; D_SOD-323
L1: 22u; XRNR4012
R11: 100; R_0402_1005Metric
R12: 12R5; R_0603_1608Metric
TP6, TP7: TestPoint; TestPoint_Pad_D1.0mm
U6: AP5725; SOT-23-6

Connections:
+5V: C41.1, L1.1, U6.6 (VIN); also elsewhere on the board
/BL_PWM: R11.1; also elsewhere on the board
/Backlight/SW: D10.2 (A), L1.2, U6.1 (SW)
/LEDA: C42.1, D10.1 (K), TP6.1, U6.5 (OVP); also elsewhere on the board
/LEDK: R12.1, U6.3 (FB); also elsewhere on the board
GND: C41.2, C42.2, R12.2, TP7.1, U6.2 (GND); also elsewhere on the board
unnamed: R11.2, U6.4 (EN)

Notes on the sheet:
R7 should be set to R = 0.25/I_{LED} For 20mA it should be as near as 12R5 as possible


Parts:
C19, C20, C21, C22, C23, C24: 100n; C_0402_1005Metric
D1, D2, D3, D4, D5, D6, D7, D8: LED; D_0805_2012Metric
JP5, JP6, JP7, JP8: SolderJumper_2_Open; SolderJumper-2_P1.3mm_Open_RoundedPad1.0x1.5mm
RN1, RN2: 270; C_ARRAY_EXB28V_PAN-L
U1: XC6SLX9-TQG144; TQFP-144_20x20mm_P0.5mm
U2: IS25LP128F-JBLE-TR; SOIC-8_5.275x5.275mm_P1.27mm

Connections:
+2V5: JP5.1 (A), JP7.1 (A); also elsewhere on the board
+3V3: C24.1, JP6.1 (A), JP8.1 (A), U2.8 (VCC); also elsewhere on the board
/CS: U1.32 (IO_L2N_3); also elsewhere on the board
/DB0: U1.24 (IO_L41P_GCLK27_3); also elsewhere on the board
/DB1: U1.23 (IO_L41N_GCLK26_3); also elsewhere on the board
/DB2: U1.22 (IO_L42P_GCLK25_TRDY2_3); also elsewhere on the board
/DB3: U1.21 (IO_L42N_GCLK24_3); also elsewhere on the board
/DB4: U1.17 (IO_L43P_GCLK23_3); also elsewhere on the board
/DB5: U1.16 (IO_L43N_GCLK22_IRDY2_3); also elsewhere on the board
/DB6: U1.15 (IO_L44P_GCLK21_3); also elsewhere on the board
/DB7: U1.14 (IO_L44N_GCLK20_3); also elsewhere on the board
/DB8: U1.12 (IO_L49P_3); also elsewhere on the board
/DB9: U1.11 (IO_L49N_3); also elsewhere on the board
/DB10: U1.10 (IO_L50P_3); also elsewhere on the board
/DB11: U1.9 (IO_L50N_3); also elsewhere on the board
/DB12: U1.8 (IO_L51P_3); also elsewhere on the board
/DB13: U1.7 (IO_L51N_3); also elsewhere on the board
/DB14: U1.6 (IO_L52P_3); also elsewhere on the board
/DB15: U1.5 (IO_L52N_3); also elsewhere on the board
/DB16: U1.2 (IO_L83P_3); also elsewhere on the board
/DB17: U1.1 (IO_L83N_VREF_3); also elsewhere on the board
/DCLK: U1.30 (IO_L36P_3); also elsewhere on the board
/DE: U1.29 (IO_L36N_3); also elsewhere on the board
/FPGA IO Bank B/CLK: U1.70 (IO_L1P_CCLK_2), U2.6 (SCK)
/FPGA IO Bank B/D_{0}: U1.64 (IO_L3N_MOSI_CSI_B_MISO0_2), U2.5 (SI)
/FPGA IO Bank B/D_{1}: U1.65 (IO_L3P_D0_DIN_MISO_MISO1_2), U2.2 (SO)
/FPGA IO Bank B/D_{2}: U1.62 (IO_L12P_D1_MISO2_2), U2.3 (~WP)
/FPGA IO Bank B/D_{3}: U1.61 (IO_L12N_D2_MISO3_2), U2.7 (~HOLD)
/FPGA IO Bank B/FPGA_{BANK2}: C19.1, C20.1, JP5.2 (B), JP6.2 (B), U1.42 (VCCO_2), U1.63 (VCCO_2)
/FPGA IO Bank B/FPGA_{BANK3}: C21.1, C22.1, C23.1, JP7.2 (B), JP8.2 (B), U1.4 (VCCO_3), U1.18 (VCCO_3), U1.31 (VCCO_3)
/FPGA IO Bank B/LED0: RN1.1 (R1.1), U1.47 (IO_L48N_RDWR_B_VREF_2)
/FPGA IO Bank B/LED1: RN1.2 (R2.1), U1.46 (IO_L49P_D3_2)
/FPGA IO Bank B/LED2: RN1.3 (R3.1), U1.45 (IO_L49N_D4_2)
/FPGA IO Bank B/LED3: RN1.4 (R4.1), U1.44 (IO_L62P_D5_2)
/FPGA IO Bank B/LED4: RN2.4 (R4.1), U1.43 (IO_L62N_D6_2)
/FPGA IO Bank B/LED5: RN2.3 (R3.1), U1.41 (IO_L64P_D8_2)
/FPGA IO Bank B/LED6: RN2.2 (R2.1), U1.40 (IO_L64N_D9_2)
/FPGA IO Bank B/LED7: RN2.1 (R1.1), U1.39 (IO_L65P_INIT_B_2)
/FPGA IO Bank B/~CS: U1.38 (IO_L65N_CSO_B_2), U2.1 (~CE)
/HS: U1.26 (IO_L37N_3); also elsewhere on the board
/SCL: U1.33 (IO_L2P_3); also elsewhere on the board
/SDA: U1.34 (IO_L1N_VREF_3); also elsewhere on the board
/VS: U1.27 (IO_L37P_3); also elsewhere on the board
/~RST: U1.35 (IO_L1P_3); also elsewhere on the board
GND: C19.2, C20.2, C21.2, C22.2, C23.2, C24.2, D1.1 (K), D2.1 (K), D3.1 (K), D4.1 (K), D5.1 (K), D6.1 (K), D7.1 (K), D8.1 (K), U2.4 (GND); also elsewhere on the board
unnamed: D1.2 (A), RN1.8 (R1.2)
unnamed: D2.2 (A), RN1.7 (R2.2)
unnamed: D3.2 (A), RN1.6 (R3.2)
unnamed: D4.2 (A), RN1.5 (R4.2)
unnamed: D5.2 (A), RN2.5 (R4.2)
unnamed: D6.2 (A), RN2.6 (R3.2)
unnamed: D7.2 (A), RN2.7 (R2.2)
unnamed: D8.2 (A), RN2.8 (R1.2)


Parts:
C13, C14, C15, C16, C17, C18: 100n; C_0402_1005Metric
C54: 10n; C_0402_1005Metric
J4: Conn_01x12; PinHeader_2x06_P1.00mm_Vertical_SMD
J5: DNM; PinHeader_2x06_P1.00mm_Vertical_SMD
U1: XC6SLX9-TQG144; TQFP-144_20x20mm_P0.5mm
U8: XLH335200.000000I

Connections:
+3V3: C13.1, C14.1, C15.1, C16.1, C17.1, C18.1, C54.1, J4.1, J4.2, U1.76 (VCCO_1), U1.86 (VCCO_1), U1.103 (VCCO_1), U1.122 (VCCO_0), U1.125 (VCCO_0), U1.135 (VCCO_0), U8.6 (VDD); also elsewhere on the board
/DVI_CEC: U1.95 (IO_L40P_GCLK11_1); also elsewhere on the board
/DVI_CK+: U1.98 (IO_L34P_1); also elsewhere on the board
/DVI_CK-: U1.97 (IO_L34N_1); also elsewhere on the board
/DVI_D0+: U1.100 (IO_L33P_1); also elsewhere on the board
/DVI_D0-: U1.99 (IO_L33N_1); also elsewhere on the board
/DVI_D1+: U1.102 (IO_L32P_1); also elsewhere on the board
/DVI_D1-: U1.101 (IO_L32N_1); also elsewhere on the board
/DVI_D2+: U1.105 (IO_L1P_1); also elsewhere on the board
/DVI_D2-: U1.104 (IO_L1N_VREF_1); also elsewhere on the board
/DVI_HPD: U1.92 (IO_L41N_GCLK8_1); also elsewhere on the board
/DVI_SCL: U1.94 (IO_L40N_GCLK10_1); also elsewhere on the board
/DVI_SDA: U1.93 (IO_L41P_GCLK9_IRDY1_1); also elsewhere on the board
/DVI_UTIL: U1.88 (IO_L42P_GCLK7_1); also elsewhere on the board
/FPGA IO Bank A/CLK_{100N}: U1.133 (IO_L34N_GCLK18_0), U8.5 (O_{2})
/FPGA IO Bank A/CLK_{100P}: U1.134 (IO_L34P_GCLK19_0), U8.4 (O_{1})
/FPGA IO Bank A/PMOD_A0: J4.5, U1.119 (IO_L63P_SCP7_0)
/FPGA IO Bank A/PMOD_A1: J4.6, U1.118 (IO_L63N_SCP6_0)
/FPGA IO Bank A/PMOD_A2: J4.7, U1.117 (IO_L64P_SCP5_0)
/FPGA IO Bank A/PMOD_A3: J4.8, U1.116 (IO_L64N_SCP4_0)
/FPGA IO Bank A/PMOD_A4: J4.9, U1.115 (IO_L65P_SCP3_0)
/FPGA IO Bank A/PMOD_A5: J4.10, U1.114 (IO_L65N_SCP2_0)
/FPGA IO Bank A/PMOD_A6: J4.11, U1.112 (IO_L66P_SCP1_0)
/FPGA IO Bank A/PMOD_A7: J4.12, U1.111 (IO_L66N_SCP0_0)
/FPGA_CLK: J5.10, U1.84 (IO_L43N_GCLK4_1); also elsewhere on the board
/FPGA_D0: J5.9, U1.83 (IO_L45P_1); also elsewhere on the board
/FPGA_D1: J5.8, U1.82 (IO_L45N_1); also elsewhere on the board
/FPGA_D2: J5.7, U1.81 (IO_L46P_1); also elsewhere on the board
/FPGA_D3: J5.6, U1.80 (IO_L46N_1); also elsewhere on the board
/FPGA_D4: J5.5, U1.79 (IO_L47P_1); also elsewhere on the board
/FPGA_D5: J5.4, U1.78 (IO_L47N_1); also elsewhere on the board
/FPGA_D6: J5.3, U1.75 (IO_L74P_AWAKE_1); also elsewhere on the board
/FPGA_D7: J5.2, U1.74 (IO_L74N_DOUT_BUSY_1); also elsewhere on the board
/FPGA_RD: J5.11, U1.85 (IO_L43P_GCLK5_1); also elsewhere on the board
/FPGA_WR: J5.12, U1.87 (IO_L42N_GCLK6_TRDY1_1); also elsewhere on the board
GND: C13.2, C14.2, C15.2, C16.2, C17.2, C18.2, C54.2, J4.3, J4.4, J5.1, U8.3 (GND); also elsewhere on the board

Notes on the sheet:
Do not mount For debugging only

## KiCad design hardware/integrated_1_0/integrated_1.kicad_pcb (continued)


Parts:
C43, C45, C46, C47, C48, C49, C50, C52, C53: 10u; C_0603_1608Metric
C44: 1u; C_0402_1005Metric
C51: 2u2; C_0603_1608Metric
L2, L4: 2u2; XRNR4012
L3: 3u3; XRNR4012
R13: 1k; R_0402_1005Metric
R14: 1R; R_0402_1005Metric
R15, R21: 100k; R_0402_1005Metric
R16, R17, R18, R22: 470k; R_0402_1005Metric
R19, R23: 105k; R_0402_1005Metric
R20: 150k; R_0402_1005Metric
TP8, TP9, TP10, TP11, TP12, TP13, TP14: TestPoint; TestPoint_Pad_D1.0mm
U7: TPS650250RHBR; IC_ADS125H01IRHBT

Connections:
+2V5: C51.1, R20.1, TP11.1, U7.16 (VLDO1); also elsewhere on the board
+3V3: C52.1, C53.1, L4.2, R15.1, R22.1, TP10.1, U7.1 (VDCDC3); also elsewhere on the board
+5V: C43.1, C45.1, C46.1, R13.1, R14.1, TP13.1, U7.4 (VINDCDC3), U7.5 (VINDCDC1), U7.15 (VINLDO), U7.28 (VINDCDC2); also elsewhere on the board
/Buck Converter/EN: R13.2, U7.17 (EN_LDO), U7.18 (EN_DCDC3), U7.19 (EN_DCDC2), U7.20 (EN_DCDC1); also elsewhere on the board
/Buck Converter/FB_{DCDC_{1}}: R16.2, R17.1, U7.9 (DEFDCDC1)
/Buck Converter/FB_{DCDC_{2}}: R18.2, R19.1, U7.22 (DEFDCDC2)
/Buck Converter/FB_{DCDC_{3}}: R22.2, R23.1, U7.32 (DEFDCDC3)
/Buck Converter/FB_{LDO1}: R20.2, R21.1, U7.11 (FB_LDO1)
/Buck Converter/L1: L2.1, U7.6 (L1)
/Buck Converter/L2: L3.1, U7.27 (L2)
/Buck Converter/L3: L4.1, U7.3 (L3)
/Buck Converter/VCC_RC: C44.1, R14.2, U7.29 (VCC)
/Buck Converter/~PWR_FAIL: R15.2, U7.21 (~PWRFAIL); also elsewhere on the board
/VCC_{AUX}: C49.1, C50.1, L3.2, R18.1, TP9.1, U7.25 (VDCDC2); also elsewhere on the board
/VCC_{INT}: C47.1, C48.1, L2.2, R16.1, TP8.1, U7.8 (VDCDC1); also elsewhere on the board
GND: C43.2, C44.2, C45.2, C46.2, C47.2, C48.2, C49.2, C50.2, C51.2, C52.2, C53.2, R17.2, R19.2, R21.2, R23.2, TP12.1, TP14.1, U7.2 (PGND3), U7.7 (PGND1), U7.13 (AGND2), U7.24 (EN_VDD_ALIVE), U7.26 (PGND2), U7.31 (AGND1), U7.33 (EP), U7.34 (EP), U7.35 (EP), U7.36 (EP), U7.37 (EP), U7.38 (EP); also elsewhere on the board

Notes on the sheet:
V_{DEFDCDC_{x}} = 0V6
Seems to default to 3V3
R_{1} = R_{2} * (V_{OUT} / V_{DEFDCDC_{x}}) - R_{2}
3V3
2V5
V_{FBLDO_{x}} = 1V0
V_{OUT} = V_{FBLDO_{x}} * (R_{1} + R_{2}) / R_{2}
This is completely overkill for this circuit. We could have gotten away with a significantly cheaper 3V3 and 1V2 supply with a few bucks, but this is honestly easier as we can just reference TI's existing reference design
R_{1} = R_{2} * (V_{OUT} / V_{FBLDO_{x}}) - R_{2}
V_{OUT} = V_{DEFDCDCx} * (R_{1} + R_{2}) / R_{2}
We are not using the VDD_{ALIVE} due to the rather low 1V output
3V3
1V2


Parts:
C3, C4, C5, C6, C7, C8, C9, C10, C11, C12: 100n; C_0402_1005Metric
U1: XC6SLX9-TQG144; TQFP-144_20x20mm_P0.5mm

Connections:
/VCC_{AUX}: C8.1, C9.1, C10.1, C11.1, C12.1, U1.19 (VCCINT), U1.28 (VCCINT), U1.52 (VCCINT), U1.89 (VCCINT), U1.128 (VCCINT); also elsewhere on the board
/VCC_{INT}: C3.1, C4.1, C5.1, C6.1, C7.1, U1.20 (VCCAUX), U1.36 (VCCAUX), U1.53 (VCCAUX), U1.90 (VCCAUX), U1.129 (VCCAUX); also elsewhere on the board
GND: C3.2, C4.2, C5.2, C6.2, C7.2, C8.2, C9.2, C10.2, C11.2, C12.2, U1.3 (GND), U1.13 (GND), U1.25 (GND), U1.49 (GND), U1.54 (GND), U1.68 (GND), U1.77 (GND), U1.91 (GND), U1.96 (GND), U1.108 (GND), U1.113 (GND), U1.130 (GND), U1.136 (GND); also elsewhere on the board

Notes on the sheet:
Datasheet mentions that VCCAUX should be 2V5 on -1 devices Luckily we have a -2 device and those support 3V3



Board: 4 copper layers, 40.0 x 100.0 mm, 129 parts (15 on the bottom side), 141 nets.

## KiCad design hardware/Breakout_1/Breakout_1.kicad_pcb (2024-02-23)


Board: 2 copper layers, 99.5 x 70.0 mm, 87 parts (0 on the bottom side), 61 nets.

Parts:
C1, C12, C22: 1u; C_0402_1005Metric
C2, C6, C9, C10, C13, C14, C15, C16, C17, C18, C19: 100n; C_0402_1005Metric
C3: 1u; C_0603_1608Metric
C4, C5: 8p; C_0402_1005Metric
C7: 10u; C_0603_1608Metric
C8: 2u2; C_0603_1608Metric
D1: LED; D_0805_2012Metric
D2: SS14; DIOM5227X270N
DS1: ST7701_IPS_3.99_TOUCH; AMPHENOL_F32Q-1A7H1-11040
J1, J2, J3, J4: Conn_01x12; PinHeader_2x06_P2.54mm_Horizontal
J5, J6, J7, J8: Conn_01x12; PinHeader_2x06_P2.54mm_Vertical
J9: USB4105-GF-A-120; USB_C_Receptacle_GCT_USB4105-xx-A_16P_TopMnt_Horizontal
J10: Conn_01x05; PinHeader_1x05_P2.54mm_Vertical
L1: 10u; L_TDK_SLF6045
R1, R2: 5k1; R_0603_1608Metric
R3: 270; R_0603_1608Metric
R4: 10K; R_0603_1608Metric
R5: DNF; R_0603_1608Metric
R6: 1k; R_0603_1608Metric
R7, R9: 1M; R_0603_1608Metric
R8: 105k; R_0603_1608Metric
SW1: DNF; PTS636 SM25J SMTR LFS
TP1, TP4, TP5, TP6, TP7, TP8, TP9, TP10, TP11, TP12, TP13, TP14, TP15, TP16, TP17, TP18, TP19, TP20, TP21, TP22, TP23, TP24, TP25, TP26, TP27, TP28, TP29, TP30, TP31, TP32, TP33, TP34, TP35, TP36, TP37, TP38, TP39, TP40, TP41: TestPoint; TestPoint_Keystone_5019_Minature_No_Silkscreen
U1: AP3015; SOT-23-5
U2: W25Q16JV; W25Q16JVUXIQ TR
U3: USBUF02W6; SOT65P210X110-6N
U4: RP2040; QFN-56-1EP_7x7mm_P0.4mm_EP3.2x3.2mm
Y1: 12MHz; ECS120836CKMTR3

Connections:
+1V1: C9.1, C10.1, C12.1, U4.23 (DVDD), U4.45 (VREG_VOUT), U4.50 (DVDD)
+3V3: C1.1, C2.1, C6.1, C7.1, C8.1, C13.1, C14.1, C15.1, C16.1, C17.1, C18.1, C19.1, C22.1, DS1.5 (VCC), DS1.39 (TP_VCC), J1.1, J1.2, J2.1, J2.2, J3.1, J3.2, J4.1, J4.2, J5.1, J5.2, J6.1, J6.2, J7.1, J7.2, J8.1, J8.2, L1.1, R5.2, TP34.1, U1.4 (~SHDN), U1.5 (VIN), U2.8 (VCC), U3.5 (3V3), U4.1 (IOVDD), U4.10 (IOVDD), U4.22 (IOVDD), U4.33 (IOVDD), U4.42 (IOVDD), U4.43 (ADC_AVDD), U4.44 (VREG_IN), U4.48 (USB_VDD), U4.49 (IOVDD)
/CS: DS1.11 (CS), J1.8, J5.8, TP7.1
/DB0: DS1.16 (DB0), J2.7, J6.7, TP12.1
/DB1: DS1.17 (DB1), J2.8, J6.8, TP13.1
/DB2: DS1.18 (DB2), J2.9, J6.9, TP14.1
/DB3: DS1.19 (DB3), J2.10, J6.10, TP15.1
/DB4: DS1.20 (DB4), J2.11, J6.11, TP16.1
/DB5: DS1.21 (DB5), J2.12, J6.12, TP17.1
/DB6: DS1.22 (DB6), J3.7, J7.7, TP18.1
/DB7: DS1.23 (DB7), J3.8, J7.8, TP19.1
/DB8: DS1.24 (DB8), J3.9, J7.9, TP20.1
/DB9: DS1.25 (DB9), J3.10, J7.10, TP21.1
/DB10: DS1.26 (DB10), J3.11, J7.11, TP22.1
/DB11: DS1.27 (DB11), J3.12, J7.12, TP23.1
/DB12: DS1.28 (DB12), J4.7, J8.7, TP24.1
/DB13: DS1.29 (DB13), J4.8, J8.8, TP25.1
/DB14: DS1.30 (DB14), J4.9, J8.9, TP26.1
/DB15: DS1.31 (DB15), J4.10, J8.10, TP27.1
/DB16: DS1.32 (DB16), J4.11, J8.11, TP28.1
/DB17: DS1.33 (DB17), J4.12, J8.12, TP29.1
/DCLK: DS1.12 (DCLK), J1.9, J5.9, TP8.1
/DE: DS1.13 (DE), J1.10, J5.10, TP9.1
/FB: R8.1, R9.2, TP40.1, U1.3 (FB)
/HS: DS1.15 (HS), J1.12, J5.12, TP11.1
/LEDA: C3.1, D2.1 (K), DS1.1 (LEDA), R7.1, TP1.1
/Microcontroller/LED_STATUS: R3.2, U4.8 (GPIO6)
/Microcontroller/QSPI_SCLK: U2.6 (CLK), U4.52 (QSPI_SCLK)
/Microcontroller/QSPI_SD0: U2.5 (DI(IO0)), U4.53 (QSPI_SD0)
/Microcontroller/QSPI_SD1: U2.2 (DO(IO1)), U4.55 (QSPI_SD1)
/Microcontroller/QSPI_SD2: U2.3 (IO2), U4.54 (QSPI_SD2)
/Microcontroller/QSPI_SD3: U2.7 (IO3), U4.51 (QSPI_SD3)
/Microcontroller/QSPI_SS: R4.1, R5.1, U2.1 (~CS), U4.56 (QSPI_SS)
/Microcontroller/USB_D+: U3.1 (D+), U4.47 (USB_DP)
/Microcontroller/USB_D-: U3.3 (D-), U4.46 (USB_DM)
/Microcontroller/USB_DR+: J9.A6 (D+), J9.B6 (D+), U3.6 (D+)
/Microcontroller/USB_DR-: J9.A7 (D-), J9.B7 (D-), U3.4 (D-)
/Microcontroller/XIN: C4.2, U4.20 (XIN), Y1.1
/Microcontroller/XOUT: R6.1, U4.21 (XOUT)
/Microcontroller/XOUT_R: C5.2, R6.2, Y1.3
/SCL: DS1.10 (SCL), J1.7, J5.7, TP6.1
/SDA: DS1.9 (SDA), J1.6, J5.6, TP5.1
/SWITCH: D2.2 (A), L1.2, TP41.1, U1.1 (SW)
/TP_INT: DS1.35 (TP_INT), J10.4, TP30.1, U4.32 (GPIO21)
/TP_RST: DS1.38 (TP_RST), J10.3, TP33.1, U4.31 (GPIO20)
/TP_SCL: DS1.37 (TP_SCL), J10.2, TP32.1, U4.30 (GPIO19)
/TP_SDA: DS1.36 (TP_SDA), J10.1, TP31.1, U4.29 (GPIO18)
/VS: DS1.14 (VS), J1.11, J5.11, TP10.1
/~RST: DS1.6 (~RST), J1.5, J5.5, TP4.1
GND: C1.2, C2.2, C3.2, C4.1, C5.1, C6.2, C7.2, C8.2, C9.2, C10.2, C12.2, C13.2, C14.2, C15.2, C16.2, C17.2, C18.2, C19.2, C22.2, D1.1 (K), DS1.2 (LEDK1), DS1.3 (LEDK2), DS1.4 (GND), DS1.34 (GND), DS1.40 (GND), J1.3, J1.4, J2.3, J2.4, J3.3, J3.4, J4.3, J4.4, J5.3, J5.4, J6.3, J6.4, J7.3, J7.4, J8.3, J8.4, J9.A1 (GND), J9.A12 (GND), J9.B1 (GND), J9.B12 (GND), J9.S1 (SHIELD), J10.5, R1.1, R2.1, R8.2, SW1.1, TP35.1, TP36.1, TP37.1, TP38.1, TP39.1, U1.2 (GND), U2.4 (GND), U3.2 (Grd), U4.57 (GND), Y1.2, Y1.4
unnamed: D1.2 (A), R3.1
unnamed: J2.5, J6.5
unnamed: J2.6, J6.6
unnamed: J3.5, J7.5
unnamed: J3.6, J7.6
unnamed: J4.5, J8.5
unnamed: J4.6, J8.6
unnamed: J9.A5 (CC1), R1.2
unnamed: J9.B5 (CC2), R2.2
unnamed: R4.2, SW1.2
unnamed: R7.2, R9.1

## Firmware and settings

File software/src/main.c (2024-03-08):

#include <stdio.h>
#include "pico/stdlib.h"
#include "pico/multicore.h"
#include "pico/binary_info.h"
#include "version.h"
#include "touch.h"
#include "usb_device.h"

#define LED_PIN 6

#define TOUCH_I2C_SDA 	18
#define TOUCH_I2C_SCL 	19
#define TOUCH_I2C_RST 	20
#define TOUCH_I2C_INT 	21

// Declare the binary info
bi_decl(bi_program_description("Touchscreen HID"));
bi_decl(bi_1pin_with_name(LED_PIN, "On-board LED"));
bi_decl(bi_program_version_string(GIT_COMMIT_HASH));
bi_decl(bi_program_build_date_string(GIT_COMMIT_DATE));
bi_decl(bi_program_url("https://github.com/Cuprum77/LCD_Driver"));
bi_decl(bi_4pins_with_names(TOUCH_I2C_SDA, "I2C SDA", TOUCH_I2C_SCL, "I2C SCL", TOUCH_I2C_RST, "I2C RST", TOUCH_I2C_INT, "I2C INT"));

/* Blink pattern
 * - 250 ms  : device not mounted
 * - 1000 ms : device mounted
 * - 2500 ms : device is suspended
 */
enum  {
  BLINK_NOT_MOUNTED = 250000,
  BLINK_MOUNTED = 1000000,
  BLINK_SUSPENDED = 2500000,
};


// LED blinker
bool led_state = false;
uint32_t interval = BLINK_NOT_MOUNTED;
uint32_t timer = 0;
void blink_led()
{
    if ((time_us_32() - timer) >= interval)
    {
        timer = time_us_32();
        led_state = !led_state;
        gpio_put(LED_PIN, led_state);
    }
}

int main()
{
    // Init stdio
    stdio_init_all();

    // Setup the blink pin
    gpio_init(LED_PIN);
    gpio_set_dir(LED_PIN, GPIO_OUT);

    // Initialize the touch controller
    touch_init(i2c1, TOUCH_I2C_SPEED, TOUCH_I2C_SDA, TOUCH_I2C_SCL, 
        TOUCH_I2C_RST, TOUCH_I2C_INT
    );

    // Init the USB
    usb_device_init();

    // Interval for transmitting touch data
    uint32_t touch_interval = 100000;
    uint32_t touch_timer = 0;
    
    while (1)
    {
        // Blink the LED
        blink_led();

        // Touch task
        usb_device_touch_data((touch_point_data_t*)touch_points, TOUCH_POINT_COUNT, touch_status_data.num_touches);
        // Device task
        usb_device_task();
        // HID task
        usb_hid_task();

        // Printout the touch data
        /*if ((time_us_32() - touch_timer) >= touch_interval)
        {
            touch_timer = time_us_32();
            printf("Status: %d, %d, %d, %d, %d\n", touch_status_data.buffer_status, touch_status_data.large_detect, touch_status_data.proximity_valid, touch_status_data.have_key, touch_status_data.num_touches);
            for (size_t i = 0; i < 5; i++)
            {
                printf("Touch %d: %d, %d, %d\n", i, touch_points[i].x, touch_points[i].y, touch_points[i].size);
            }
        }*/
    }
}

//--------------------------------------------------------------------+
// Device callbacks
//--------------------------------------------------------------------+

// Invoked when device is mounted
void tud_mount_cb(void)
{
    interval = BLINK_MOUNTED;
}

// Invoked when device is unmounted
void tud_umount_cb(void)
{
    interval = BLINK_NOT_MOUNTED;
}

// Invoked when usb bus is suspended
// remote_wakeup_en : if host allow us  to perform remote wakeup
// Within 7ms, device must draw an average of current less than 2.5 mA from bus
void tud_suspend_cb(bool remote_wakeup_en)
{
    (void) remote_wakeup_en;
    interval = BLINK_SUSPENDED;
}

// Invoked when usb bus is resumed
void tud_resume_cb(void)
{
    interval = tud_mounted() ? BLINK_MOUNTED : BLINK_NOT_MOUNTED;
}

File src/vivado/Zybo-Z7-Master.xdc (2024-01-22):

## This file is a general .xdc for the Zybo Z7 Rev. B
## It is compatible with the Zybo Z7-20 and Zybo Z7-10
## To use it in a project:
## - uncomment the lines corresponding to used pins
## - rename the used ports (in each line, after get_ports) according to the top level signal names in the project

##Clock signal
set_property -dict { PACKAGE_PIN K17   IOSTANDARD LVCMOS33 } [get_ports { sysclk }]; #IO_L12P_T1_MRCC_35 Sch=sysclk
create_clock -add -name sys_clk_pin -period 8.00 -waveform {0 4} [get_ports { sysclk }];


##Button
set_property -dict { PACKAGE_PIN K18   IOSTANDARD LVCMOS33 } [get_ports { btn }]; #IO_L12N_T1_MRCC_35 Sch=btn[0]


##LEDs
set_property -dict { PACKAGE_PIN M14   IOSTANDARD LVCMOS33 } [get_ports { led[0] }]; #IO_L23P_T3_35 Sch=led[0]
set_property -dict { PACKAGE_PIN M15   IOSTANDARD LVCMOS33 } [get_ports { led[1] }]; #IO_L23N_T3_35 Sch=led[1]
set_property -dict { PACKAGE_PIN G14   IOSTANDARD LVCMOS33 } [get_ports { led[2] }]; #IO_0_35 Sch=led[2]
set_property -dict { PACKAGE_PIN D18   IOSTANDARD LVCMOS33 } [get_ports { led[3] }]; #IO_L3N_T0_DQS_AD1N_35 Sch=led[3]


##HDMI RX
set_property -dict { PACKAGE_PIN W19   IOSTANDARD LVCMOS33 } [get_ports { hdmi_rx_hpd }]; #IO_L22N_T3_34 Sch=hdmi_rx_hpd
set_property -dict { PACKAGE_PIN W18   IOSTANDARD LVCMOS33 } [get_ports { hdmi_rx_scl }]; #IO_L22P_T3_34 Sch=hdmi_rx_scl
set_property -dict { PACKAGE_PIN Y19   IOSTANDARD LVCMOS33 } [get_ports { hdmi_rx_sda }]; #IO_L17N_T2_34 Sch=hdmi_rx_sda
set_property -dict { PACKAGE_PIN U19   IOSTANDARD TMDS_33     } [get_ports { hdmi_rx_clk_n }]; #IO_L12N_T1_MRCC_34 Sch=hdmi_rx_clk_n
set_property -dict { PACKAGE_PIN U18   IOSTANDARD TMDS_33     } [get_ports { hdmi_rx_clk_p }]; #IO_L12P_T1_MRCC_34 Sch=hdmi_rx_clk_p
set_property -dict { PACKAGE_PIN W20   IOSTANDARD TMDS_33     } [get_ports { hdmi_rx_n[0] }]; #IO_L16N_T2_34 Sch=hdmi_rx_n[0]
set_property -dict { PACKAGE_PIN V20   IOSTANDARD TMDS_33     } [get_ports { hdmi_rx_p[0] }]; #IO_L16P_T2_34 Sch=hdmi_rx_p[0]
set_property -dict { PACKAGE_PIN U20   IOSTANDARD TMDS_33     } [get_ports { hdmi_rx_n[1] }]; #IO_L15N_T2_DQS_34 Sch=hdmi_rx_n[1]
set_property -dict { PACKAGE_PIN T20   IOSTANDARD TMDS_33     } [get_ports { hdmi_rx_p[1] }]; #IO_L15P_T2_DQS_34 Sch=hdmi_rx_p[1]
set_property -dict { PACKAGE_PIN P20   IOSTANDARD TMDS_33     } [get_ports { hdmi_rx_n[2] }]; #IO_L14N_T2_SRCC_34 Sch=hdmi_rx_n[2]
set_property -dict { PACKAGE_PIN N20   IOSTANDARD TMDS_33     } [get_ports { hdmi_rx_p[2] }]; #IO_L14P_T2_SRCC_34 Sch=hdmi_rx_p[2]
set_property CLOCK_DEDICATED_ROUTE FALSE [get_nets { hdmi_rx_scl }]; # Why should this be treated as a clock signal?

##HDMI RX CEC (Zybo Z7-20 only)
set_property -dict { PACKAGE_PIN Y8    IOSTANDARD LVCMOS33 } [get_ports { hdmi_rx_cec }]; #IO_L14N_T2_SRCC_13 Sch=hdmi_rx_cec
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

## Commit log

2024-01-05 first breakout board
    [Breakout_1.kicad_pcb, Breakout_1.kicad_sch, mcu.kicad_sch]
2024-01-05 regenerated the gerber
2024-01-08 spi hardware
2024-01-08 updated the spi to follow university guidelines
2024-01-08 added the assembler for the psuedo assembly code
2024-01-08 updated the spi readme with docs
2024-01-09 updated the readme to reflect current state
2024-01-14 added the spi simulation files
2024-01-14 added the SPI UVVM testbench and relevant files
2024-01-14 minor corrections of the spi simulation
2024-01-14 further restructuring
    [Breakout_1.kicad_pcb, Breakout_1.kicad_sch, mcu.kicad_sch]
2024-01-14 fixing wrong case leftover from restructuring
2024-01-14 added known issues to the pcb page
2024-01-16 added vivado project
    [pmod_inline_buffer.kicad_pcb, pmod_inline_buffer.kicad_sch]
2024-01-17 crude start
    [pmod_inline_buffer.kicad_pcb]
2024-01-21 passed variables up, fixed de signal fault
2024-01-22 functional hdmi prototype
2024-01-26 added the stand model
    [stand.stl]
2024-01-26 removed old folder
    [pmod_inline_buffer.kicad_pcb, pmod_inline_buffer.kicad_sch]
2024-01-27 simulation has been updated to reflect changes in the spi file
2024-02-11 completed the touch library, added interrupts to fetch new data
2024-02-11 current build, may not work
2024-02-23 updated kicad files to 8.0.0
    [Breakout_1.kicad_pcb]
2024-02-23 updated schematic files to kicad 8.0.0
    [Breakout_1.kicad_sch]
2024-02-23 updated sheet file to kicad 8.0.0
    [mcu.kicad_sch]
2024-02-23 added bom file
    [Breakout_1.csv]
2024-03-01 moved tinyusb cbs to usb_device.c, changed to work on Pico for rapid prototyping
2024-03-02 updated to only read if ready, fixing missing status register
    [touch.c]
2024-03-08 shotgun method of bug solving (didnt work)
    [main.c]
2024-03-11 added the work in progress second pcb
    [backlight.kicad_sch, fpga_io.kicad_sch, fpga_io_2.kicad_sch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]
2024-03-11 renaming a few pins
    [backlight.kicad_sch, integrated_1.kicad_sch, rp2040.kicad_sch]
2024-03-22 seperated converter from fpga power sheet
    [fpga_power.kicad_sch]
2024-03-22 added a buck converter
    [buck_power.kicad_sch]
2024-03-22 moved usb resistors inside the rp2040 sheet
    [rp2040.kicad_sch]
2024-03-22 automatic kicad reference update
    [backlight.kicad_sch]
2024-03-22 hooked up dvi and rp2040 to fpga
    [fpga_io_bank_a.kicad_sch]
2024-03-22 hooked up display to fpga
    [fpga_io_bank_b.kicad_sch]
2024-03-22 updated gitignore with kicad plugin
2024-03-22 added top level connections between the fpga modules
    [integrated_1.kicad_sch]
2024-03-22 created a rudementary shape and added a few parts and tracks to visualize pcb
    [integrated_1.kicad_pcb]
2024-03-23 rearranged the pinout to make more sense
    [fpga_io_bank_a.kicad_sch, fpga_io_bank_b.kicad_sch, integrated_1.kicad_pcb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]
2024-03-24 reannotated schematic
    [backlight.kicad_sch, buck_power.kicad_sch, fpga_io_bank_a.kicad_sch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]
2024-03-24 started the layout process + added new hdmi and usb connectors
    [integrated_1.kicad_pcb]
2024-04-04 added cheap eeprom
    [rp2040.kicad_sch]
2024-04-04 added async reset
    [fpga_jtag.kicad_sch]
2024-04-04 added leds
    [fpga_io_bank_b.kicad_sch]
2024-04-04 removed gpio references
    [fpga_io_bank_a.kicad_sch]
2024-04-04 added sources for silkscreen "art"
2024-04-04 created a rough 3d model of the display for improved visualization
    [LCD_3_99.step]
2024-04-04 improved top level visually
    [integrated_1.kicad_sch]
2024-04-04 kicad data that keeps changing by a few variables every time
2024-04-04 significant progress in the layout has been made, close to completion
    [integrated_1.kicad_pcb]
2024-04-05 finalizing the schematic and layout
    [fpga_io_bank_a.kicad_sch, fpga_io_bank_b.kicad_sch, fpga_jtag.kicad_sch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]
2024-04-11 added testpoints
    [backlight.kicad_sch, buck_power.kicad_sch, fpga_io_bank_a.kicad_sch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]
2024-04-19 exported 3d models + added date stamp
    [backlight.kicad_sch, buck_power.kicad_sch, integrated_1.kicad_pcb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]
2024-04-19 removed depreciated files
    [fpga_io.kicad_sch, fpga_io_2.kicad_sch, power.kicad_sch]
2024-04-22 fixed critical issue - display connector was mirrored
    [fpga_io_bank_b.kicad_sch, integrated_1.kicad_pcb, integrated_1.kicad_sch]
2024-05-05 adding the kicad-render script
2024-05-05 adding the breakout board images
2024-06-27 renamed the revision 1 of the integrated solution to integrated_1_0
    [LCD_3_99.step, backlight.kicad_sch, buck_power.kicad_sch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]
2024-06-27 created a revision 1.1 of the pcb design
    [LCD_3_99.step, backlight.kicad_sch, buck_power.kicad_sch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]
2024-06-28 implemented changes as suggested by https://github.com/diminDDL
    [fpga_io_bank_a.kicad_sch, integrated.kicad_pcb, rp2040.kicad_sch]
2024-06-28 added a readme for the newest pcb
2024-06-28 included bitfiles as well as the missing constraint file
    [Zybo-Z7-Master.xdc]
2024-06-28 changed copper pour to not have thermal reliefs (it looked nicer)
    [integrated.kicad_pcb]
